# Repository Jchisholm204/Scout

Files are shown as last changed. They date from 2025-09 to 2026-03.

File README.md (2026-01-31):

# Scout - Autonomous UAV Project

Scout is a quad rotor UAV capable of autonomous navigation in small spaces without the use of GNSS signals.
This is accomplished using a combination of SLAM and low level control algorithms for local and global positioning.

## Repo Organization
The base level of this repo is designed to follow the format of a ROS2 Project.
All code is encapsulated within ROS nodes within the [`src`](./src) folder.
Project documentation can found under [`docs`](./docs), while most other docs are placed with the code they are documenting.
Scripts, including build and launch scripts, can be found under [`scripts`](./scripts), while Python Launch files can be found under [`launch`](./launch).
Finally, the PCB design is available under [`PCB_Scout`](./PCB_Scout), and embedded code is placed under [`src/control_board`](./src/control_board/firmware)

## Building

### Dependencies
- ROS2 Humble
- arm-none-eabi-gcc
- CLANG/CLANG-15
- RViZ
- [Liftoff Steam Game](https://store.steampowered.com/app/410340/Liftoff_FPV_Drone_Racing/) (for running the simulation)

### Building ROS Nodes
The ROS build is handled by the [`build.sh`](./scripts/build.sh) script and the top level `Makefile`.
To build the ROS nodes, run:
```sh
make
```

To generate a clean build, run:
```sh
make clean all
```

#### Adding to the build
By default, the ROS build system is only configured to build the specified nodes for the current target system, set by the system `HOSTNAME`.
Package names listed under `PKGS_COMMON` will be built on all systems.
Some packages are platform specific, and thus are specified under `PKGS_{PLATFORM}`.
To add a platform, add a new hostname declaration, a new platform specific package list, and adjust the `if` condition at the bottom of [`build.sh`](./scripts/build.sh)

### Building Embedded Code
The embedded code is not built with the ROS nodes.
Do not attempt to add the embedded code to the ROS build system.
ROS will struggle to comprehend the cross compilation and linking used in the embedded codebase.

To build the embedded code, refer to the top level `Makefile` within the [Firmware](./src/control_board/firmware) folder.
After installing `arm-none-eabi-gcc`, the embedded code can typically be built and flashed with:
```sh
make build
# For Flashing using the Linux Open Source st-flash tool
make st-flash-lin
# For Flashing using the ST utility on Windows
make st-flash-win
# For Flashing using a black magic probe
make BlackMagic-flash
```

**Building on Windows:**
When building on Windows -w- VS Code, incorrectly configured environment variables can cause build environment to default to `MSVC` rather than the `arm-none-eabi` compiler.
This **will** cause the build to fail.

To resolve this error, either remove the `MSVC` compiler, or use the `CMakeLists` plugin within VS Code to correctly configure the compiler to `arm-none-eabi-gcc`.

## Simulation/HILT
Hardware In the Loop testing is possible through the Liftoff FPV Flight simulator.
First, download and install Liftoff from the [Steam Store](https://store.steampowered.com/app/410340/Liftoff_FPV_Drone_Racing/).
After installing, follow the directions within [Jchisholm/LiftoffSimulator](https://github.com/Jchisholm204/LiftoffSimulator) to build and install the required modifications.

Basic simulation is possible without installing the modifications, however, LiDAR data, along with the [`simulation/lidarstreams`](./src/simulation/lidarstreams) node will fail to function.

After Liftoff has been configured, launch the simulator, followed by the [`sim_rviz.py`](./launch/sim_rviz.py) Launch Script.
This script can be launched with:
```sh
ros2 launch ./launch/sim_rviz.py
```

After launching, RViZ should display the drone, along with simulated LiDAR data.
Note that with the current state of the simulation mod, the LiDAR data is directly correlated to the in-game camera angle.
Therefore, for accurate testing, set the in-game camera angle to zero (0).

## Flight Stack
### ROS
The highest level control algorithms.
Not designed to run in real-time (ROS cannot handle real-time scheduling).

### Control Board
Low Level Collision Avoidance and flight control algorithms.
The Control Board handles real-time flight kinematics based off of LiDAR data and feedback from the FC.

### INAV (FC)
The INAV project was used as the firmware for the flight controller.
The INAV stack handles the lowest level of flight kinematic control and motor control.

### Drone
 - SpeedyBeeF405 V4 FC
 - SpeedyBee 65A 3-6S ESC
 - 10" Frame
 - 800KVA Motors

### Jetson
 - Jetson Nano
 - Quad Core Cortex-A57
 - Nvidia Maxwell GPU (256 Cuda Cores)
 - Ubuntu 22.04.5 LTS "Jammy Jellyfish"

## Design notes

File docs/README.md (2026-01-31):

# Scout - Autonomous UAV Project
This page serves as the project homepage for the Autonomous UAV drone named Scout.

## Simulation
- [Liftoff Simulator](./Liftoff Simulator.md)
- [Simulation LiDAR Processing](./Embedded/Simulation LiDAR Processing.md)
## Embedded Control Board
- [Serial Layer](./Embedded/Serial Layer.md)
- [FreeRTOS](./Embedded/FreeRTOS.md)
- [Control Task](./Embedded/Control Task.md)
- [AntiGravity Controller](./Embedded/AntiGravity Controller.md)
- [USB Interface](./Embedded/USB Interface.md)
- [Crossfire Interface](./Embedded/Crossfire Interface.md)

## High-Level Control (ROS)

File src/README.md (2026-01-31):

# Packages
Each package contains relevant documentation in its directory.
See [this link](https://jchisholm204.github.io/posts/ros_project_templating/) for how to structure ROS packages/nodes.

### ([`control_board`](./control_board))
Contains the [embedded code](./control_board/firmware) and [driver](./control_board/driver) for the control PCB.
This board handles the low-level control and obstacle avoidance.

### [`simulation`](./simulation)
Contains the bridge code that allows ROS to interact with the Liftoff simulator.

### [`controllers`](./controllers)
High level controllers and control algorithms.
Includes planning algorithms.

### Interfaces (deprecated)
Interfaces used for interacting directly with sensors, removing the control board from the critical path.

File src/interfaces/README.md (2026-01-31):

# LEGACY
## Interfaces
The interfaces package handles all sensor/device interfacing.

### `inav_bridge`
The `inav_bridge` node handles interfacing ROS with INAV on the FC.
Receives generic `Vector3` commands on target angles to set the drone to.
Publishes IMU, Gyro, RSSI, and other data.
#### Deps
- libmsp (included in the project directory as a git submodule)

#### Parameters
- `fc_path`:
    - Desc: UNIX file path to the FC file descriptor
    - Type: `std::string`
    - Default: `/dev/ttyACM0`
- `fc_baud`:
    - Desc: Baud rate to use when interacting with the FC
    - Type: `uint64_t`
    - Default: `921600`
- `wd_timeout`:
    - Desc: Watch-Dog timeout value
    - Type: `uint64_t` (ms)
    - Default: `500`
- `pub_prefix`:
    - Desc: Prefix applied to all ROS/INAV messages
    - Type: `std::string`
    - Default: `inav`
- `movement_topic`:
    - Desc: Topic name to receive movement messages (`Vector3`)
    - Type: `std::string`
    - Default: `movement`
- `arm_topic`:
    - Desc: Topic name to receive arming messages over (`Bool`)
    - Type: `std::string`
    - Default: `armed`
- `fall_time`:
    - Desc: Time (in s) to allow the drone to fall on low throttle before shutting down during failure.
    - Type: `uint64_t` (seconds)
    - Default: `5`
- `fall_speed`:
    - Desc: Throttle speed to use when falling during failure
    - Type: `uint64_t`
    - Default: `1500`
    - Max: `2000`
    - Min: `0`

#### Topics
All topics are published with the naming convention `/prefix/topic`.
- `imu`: Gravity Readings in x, y, z format
- `gyro`: Rotational Readings in yaw, pitch, roll format
- `quat`: Orientation of the drone in quat format
- `batt`: Battery State (Voltage, Current, mAh used)
- `motor_speed`: Motor Speed (in RPM) reported by the ESC
- `altitude`: Barometric Altitude Reading
- `rssi`: RSSI Signal Strength (0-100%)

### `rplidar_bridge`
Handles interfacing between the RPLiDAR and ROS.

#### Parameters
- `lidar_path`:
    - Desc: UNIX File path to the LiDAR file descriptor
    - Type: `std::string`
    - Default: `/dev/ttyUSB0`
- `lidar_baud`:
    - Desc: Baud rate to use with the LiDAR (Change with Caution)
    - Type: `uint64_t`
    - Default: `460800`
- `pub_prefix`:
    - Desc: Publish Prefix (lidar topic name)
    - Type: `std::string`
    - Default: `lidar`
- `frame_id`:
    - Desc: Base Frame ID for RVIZ
    - Type: `std::string`
    - Default: `map`
- `pub_rate`:
    - Desc: Lidar Message Publish rate (in ms)
    - Type: `uint64_t`
    - Default: `50`
    - Max: `1000`
    - Min: `10`
- `lidar_mode`:
    - Desc: Lidar Mode to be used
    - Type: `uint64_t`
    - Default: `0`
    - Max: Depends on model of LiDAR
    - Min: `0`

#### Topics
- `$(pub_prefix)`: Laser Scan message with LiDAR Data

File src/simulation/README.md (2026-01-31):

# Simulation - Liftoff Simulator Bridge
This package acts as a bridge between the Liftoff FPV flight simulator and ROS.

To read more about how to set up the simulator, see [this writeup](https://jchisholm204.github.io/posts/liftoffsim/).

## `simulation/control`
The simulation control node serves to inject control node into the Liftoff Simulator.
It does this by emulating a virtual controller device that Liftoff sees as a generic joystick.

To send commands to the Simulator, create a node that publishes a `geometry_msgs::Quaternion` message with the format:
```
x: forwards velocity
y: sideways velocity
z: vertical velocity
w: rotational velocity
```
The control node expects that all values within the Quaternion are capped between [-1, 1].

### Parameters
- `crtl_topic`: string - topic name to listen to control commands on

### Topics
- `ctrl_topic`: Quaternion - Control Command

## `simulation/lidarstreams`
The simulation `lidarstreams` node relays UDP LiDAR data outputs from the Liftoff simulator into the ROS network in the form of Laser Scan messages.

### Parameters
- `lidar_front_name`: string - topic name for the front LiDAR
- `lidar_vertical_name`: string - topic name for the vertical LiDAR
- `pub_rate`: milliseconds (int) - the rate at which LiDAR messages are published

### Topics
- `lidar_front_name`: `LaserScan` - Front LiDAR Laser Scan (pub)
- `lidar_vertical_name`: `LaserScan` - Vertical LiDAR Laser Scan (pub)

## `simulation/telemetry`
Publishes the Telemetry information from the Liftoff Simulator as ROS Telemetry messages

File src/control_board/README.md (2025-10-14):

# Control Board

## Include
Shared `include` directory for embedded and driver sides.

## Driver
ROS side driver code.

## Firmware
Embedded STM32 Firmware.
This code must not be compiled with ROS.

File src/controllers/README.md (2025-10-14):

## Controllers
The Controllers package handles all the control algorithms applied to the drone.

### `gravitational`
Gravitational based motion controller.
Accepts in a directional vector on where to move.
Produces stick outputs that can be applied to the drone.
Uses Lidar data avoid objects.

#### Parameters
- `imu_topic`:
    - Desc: Topic name of the IMU topic
    - Type: `std::string`
    - Default: `/inav/imu`
- `gyro_topic`:
    - Desc: Topic name for the drone gyro
    - Type: `std::string`
    - Default: `/inav/gyro`
- `battery_topic`:
    - Desc: Topic name for the drone battery
    - Type: `std::string`
    - Default: `/inav/batt`
- `motor_topic`:
    - Desc: Topic name for the drone motor average rpm
    - Type: `std::string`
    - Default: `/inav/mtr`
- `altitude_topic`:
    - Desc: Topic name for the drone barometric altitude
    - Type: `std::string`
    - Default: `/inav/altitude`
- `hor_lidar_topic`:
    - Desc: Topic name the horizontal LiDAR data
    - Type: `std::string`
    - Default: `/lidar`
- `ver_lidar_topic`:
    - Desc: Topic name the vertical LiDAR data
    - Type: `std::string`
    - Default: `/verdar`
- `target_topic`:
    - Desc: Topic name to listen for target positions on
    - Type: `std::string`
    - Default: `/gtarget`
- `movement_topic`:
    - Desc: Topic name top send out drone movement commands on
    - Type: `std::string`
    - Default: `/inav/movement`
- `arming_topic`:
    - Desc: Topic name top send out drone arming commands on
    - Type: `std::string`
    - Default: `/inav/armed`
- `collide_max`:
    - Desc: Maximum range value to consider points for collision detection
    - Type: `float` (meters)
    - Default: `0.8f`
- `hover_alt`:
    - Desc: Minimum distance from the ground to overcome ground effects
    - Type: `float` (meters)
    - Default: `0.5f`
- `log_level`:
    - Desc: Logging Level to use
    - Type: `std::string` [`none`, `info`, `warning`, `error`]
    - Default: `none`
- `horizontal_weight`:
    - Desc: Weighting applied to horizontal LiDAR readings
    - Type: `float` (meters)
    - Default: `1.0f`
- `vertical_weight`:
    - Desc: Weighting applied to vertical LiDAR readings
    - Type: `float` (meters)
    - Default: `1.0f`
- `target_weight`:
    - Desc: Weighting applied to the target position 
    - Type: `float` (meters)
    - Default: `1.0f`
- `hover_weight`:
    - Desc: Weighting applied to the hover distance
    - Type: `float` (meters)
    - Default: `1.0f`

#### Topics
- `[movement_topic]`: Publishes stick commands
- `[arming_topic]`: Topic to send the arming messages over
- `[target_topic]_mk`: Publishes a `visualization_msgs::msg::Marker` for Rviz compatibility

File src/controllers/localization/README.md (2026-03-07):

# Localization Controller

Operates on LiDAR points from either the drone or simulation to generate "walls."
Walls are either "valid," representing free space, or "invalid," representing actual physical walls seen by the LiDAR sensors.

**Requires:**
The `laser_segmentation` node to be online.

The `laser_segmentation` node generates a base set of segments from the LiDAR data.
This node uses that data to generate "walls" by merging and separating segments.
This node also applies a hysteresis filter to smooth out jumpy walls and prevent false positives for unexplored areas.

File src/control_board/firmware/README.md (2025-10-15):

# Scout - Central Control Board

USB Operated control board for the Scout Capstone Project.

- Control interfaces are exposed over a USB CDC interface build with the IAD mechanism.
- Virtual COM port implemented for error feedback through USB CDC (IAD)

## USB Device Specifications
(exposed from the viewpoint of the host as per USB IF specifications)
- Vendor ID: 0xFFFE
- Product ID: 0x0A4D
- Virtual COM port (CDC)
    - NTF Interface Number: 0x00
    - Data Interface Number: 0x01
    - Data RX EP: 0x01
    - Data TX EP: 0x81
    - Maximum Data Packet Size: 0x40
    - NTF EP: 0x82
    - Maximum NTF Packet Size: 0x08
- Control Endpoint (CDC)
    - NTF Interface Number: 0x02
    - Data Interface Number: 0x03
    - Data RX EP: 0x03
    - Data TX EP: 0x83
    - Maximum Data Packet Size: 0x40
    - NTF EP: 0x84
    - Maximum NTF Packet Size: 0x08

## Firmware
The application firmware is located under `core`.
Documentation for working within the core is in [`core/README.md`](./core/README.md).

### Dependencies
- FreeRTOS (`FreeRTOS/`)
- CMSIS (`vendor/`)
- GNU Make
- CMake
- ARM GCC Cross-Compiler

> [!WARNING]
> You must install the `arm-none-eabi` tool-chain before attempting to build.
> This tool-chain can be found on the [ARM Developer Website](https://developer.arm.com/downloads/-/gnu-rm)

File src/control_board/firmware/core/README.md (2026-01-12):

# Core Code README
The "Core Code" encompasses all application specific code.
For boot sequence or linker documentation, see the [Vendor Documentation](../vendor/README.md).
For FreeRTOS documentation, see the [FreeRTOS Website](https://www.freertos.org/).

## Configuration
Located under `include/config/`, there are many configuration files used for the HAL, OS, and pin-maps.

### Boards
The boards folder, located under `include/config/boards`, gives developers an opportunity to easily test code on multiple boards.
To add to the boards list, first create the board and its pin-maps following the format from the existing boards.
Then, add the board to the list of boards under `include/config/pin_cfg.h`.

### NVIC
Contains the Nested Vector interrupt Controller (NVIC) configuration.
Messing with this file can cause FreeRTOS stalls and hard faults.

## OS
Files part of the OS include the FreeRTOS Scheduler, `C` files under the OS folder in `src`, and the HAL.
Additionally, the `FreeRTOSConfig.h` file under `include/config`.

Any file falling in the OS category should not be modified.
These files allow the base system to function correctly.
Modifying them could introduce unintended errors or faults that are difficult to diagnose.

### StdIO
To configure the Standard Input/Output port, use the function `register_stdio` provided by `syscalls.h`.
This function should be called once by the main function.
If not initialized, IO calls such as `printf` will return an error.

## Drivers
Drivers are the middleware.
They exist to provide access control between FreeRTOS tasks and the STM32 hardware.
The is project contains UART, CAN, and USB Drivers.
The drivers folder should contain only STM32 drivers that interact with the STM32 HAL.
Other drivers, such as device drivers, should be placed under [interfaces](#interfaces).

### UART
The UART driver, titled `Serial`, acts as a middleware allowing UART ports to be shared between FreeRTOS Tasks.
The Serial layer also enables `C` functions such as `printf`.
To use a Serial port for printf, initialize it in `main.c`, then initialize it as the standard IO port via `register_stdio`.

Writing to UART is a blocking operation.
Writing can be performed through the Serial Driver layer, which contains an access mutex.
Therefore, Serial ports can be shared between multiple FreeRTOS Tasks.

To read from a UART port, create a [FreeRTOS Stream Buffer](https://freertos.org/Documentation/02-Kernel/04-API-references/08-Stream-buffers/00-RTOS-stream-buffer-API).
The buffer should be created statically, and set up for whatever application specific purpose is needed.
To attach the buffer to the Serial port, call `serial_attach`.
Only one FreeRTOS task may attach a read buffer at the same time.
Read buffers are filled on UART interrupts, which are enabled automatically when a buffer is attached, and disabled automatically when a buffer is detached.

> **Update:** *(Jan 12, 2026)*
> The Serial layer was changed from being globally accessible to a private implementation.
> This is to reduce the risk of code errors and interfering writes for devices that operate over UART.
> The CAN Layer has not yet had this change applied.

### CAN
The CAN Bus driver allows tasks to register `CanMailbox_t` structures with it.
A mailbox is tailored to a specific CAN ID.
When a CAN Bus interrupt occurs, the message is forwarded to the CAN Task, which then deposits messages into mailboxes.
Tasks can read from the mailbox at any time, or block waiting for an RX event with `can_mailbox_wait`.
Tasks may choose to block indefinitely waiting for an RX event.
If blocking waiting for an RX event, the task will be woken up once the CAN task has finished.
The CAN task can register a maximum of `MAX_MAILBOXES`.
Adjust this define statement to enable more mailboxes.
This will use additional memory.

### USB
The USB Drivers used in this project are from the libusb_stm32 library.
Most of the USB Driver and HAL are directly taken from the USB CDC Demo project.
Only minor modifications have been made to the library in this project.
See [this GitHub repository for more information.](https://github.com/dmitrystu/libusb_stm32)

## User Code

### Protocols
The protocols folder has been set aside for application specific drivers and protocols.
This should not be confused with the `drivers` folder, which is used for system level drivers.

### Tasks
All user tasks should be placed within the `tasks` folder.

All tasks should follow the same generic base structure:

```c
typedef struct {
    TaskHandle_t tsk_hndl;
    StaticTask_t tsk_buf;
    StackType_t tsk_stack[STACK_SIZE];
    ...
} myTask;

void *myTask_init(myTask *, ...){
    ...
    xTaskCreateStatic(...);
    ...
}
```

This structure allows all task data and runtime nonsense to be statically initialized in main.

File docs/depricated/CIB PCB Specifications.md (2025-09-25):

The Central Interface Board (CIB) handles low level drone operation including collision avoidance, flight execution, and system monitoring.
*Note: Flight kinematics are out of the scope for this board.*

# Interfaces
- 1x USB FS (over USBC) [[CIB USB Spec]]
	- PG Excluded
- 6x UART/USART (with 5V PG)
	- 2x RPLidar Connections [[RPLiDAR]]
	- 1x MSP connection
	- 1x CRSF OUT connection
	- 2x Debug/EPS
- 8x analog
	- Scaling voltage dividers for up to 8S battery monitoring
- 5V5A generic power connection (for Jetson Nano)

## Battery Monitoring
Multi cell batteries typically contain balance leads.
For a 4S battery, the lead pattern would be as follows:
- GND
- 4.2V
- 8.4V
- 12.6V
- 16.8V
For any battery with a higher number of cells, the pattern continues increasing 4.2V (Max cell voltage) for every connection.
The battery monitor must use the correct voltage dividers to accurately sample battery cell voltages.

# Chips
- An `STM32F446` should be used as the MCU.
- LLS's are not required for CSRF, RPLiDARS, or FC interactions.
- An IMU with internal filtering should be selected

# Power
The voltage rails and connected devices are listed below with amperage requirements
- VBatt
	- Drone (~A)
- 5V0
	- Jetson (5A)
	- 2x RPLidar (4A)
	- CSRF Module (500mA)
- 3V3
	- STM32F446 (1A)

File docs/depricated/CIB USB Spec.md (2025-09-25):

# Device Specifications
- Vendor ID: `0xFFFE`
- Product ID: `0xD40E`
# EP Specifications
The following lists the endpoint specifications for the USB interface.
RX/TX pairs are listed from the perspective of the host as per USB IF specifications.
## Control/Planning (CDC ACM)
- NTF Interface Number: `0x00`
- Data Interface Number: `0x01`
- Data RX EP: `0x01`
- Data TX EP: `0x81`
- Maximum Packet Size: `0x40`
- NTF EP: `0x82`
- Maximum NTF Packet Size: `0x08`
### TX Interface
- Target Type - `(u8)enum`
	- Velocity - Sets the target velocity of the drone
	- Positional - Sets the target position of the drone
	- Hold - Drone will ignore position and attempt to hold the current position
- Target X - `float32`
- Target Y - `float32`
- Target Z - `float32`
- Target W (yaw) - `float32`
- Flags
	- Arm Drone
	- Disarm Drone
	- Reset 1
	- Reset 0
	- Execute Fail Safe
	- Valid 0
	- Valid 1
### RX Interface
- $A_x$ (Acceleration in X) - `float32`
- $A_y$ (Acceleration in Y) - `float32`
- $A_z$ (Acceleration in Z) - `float32`
- $A_w$ (Acceleration in W) - `float32`
- Battery Voltage - `float32`
- Flags - `u8`
	- Stopped before Collision
	- Drone Armed
	- FC Error
	- CIB Error
	- Valid 0
	- Valid 1

## RPLiDAR Hor
Forwards the RPLiDAR data from the horizontal lidar.
- NTF Interface Number: `0x02`
- Data Interface Number: `0x03`
- Data RX EP: `0x03`
- Data TX EP: `0x83`
- Maximum Packet Size: `0x40`
- NTF EP: `0x84`
- Maximum NTF Packet Size: `0x08`
## RPLiDAR Ver
Forwards the RPLiDAR data from the vertical lidar.
- NTF Interface Number: `0x04`
- Data Interface Number: `0x05`
- Data RX EP: `0x05`
- Data TX EP: `0x85`
- Maximum Packet Size: `0x40`
- NTF EP: `0x86`
- Maximum NTF Packet Size: `0x08`

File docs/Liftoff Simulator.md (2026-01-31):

Liftoff is first-person drone racing simulator designed for human pilots to explore flying.
To test autonomous drone control, I repurposed Liftoff to act as a high-fidelity testing environment.

While liftoff is designed primarily for human pilots, it can be configured to expose basic telemetry data over UDP.
Additionally, the game is written in Unity, allowing further data to be exposed through modifying the game files.
Finally, control input can be supplied to the game through a virtual controller.
Therefore, the game can be used as a hyper-realistic simulator for testing autonomous flight control algorithms.

## Basic Telemetry Output
By default, Liftoff can be configured to expose basic telemetry data.
For a full explanation on how to enable Liftoff's drone telemetry feature, see [this post on the Steam community forum.](https://steamcommunity.com/sharedfiles/filedetails/?id=3160488434)

On Linux, all telemetry data can be exposed by placing the following inside of  `~/.config/unity3d/LuGus Studios/Liftoff/TelemetryConfiguration.json`.

```json
{ 
	"EndPoint": "127.0.0.1:9001", 
	"StreamFormat": [ 
		"Timestamp", 
		"Position", 
		"Attitude", 
		"Velocity", 
		"Gyro", 
		"Input", 
		"Battery", 
		"MotorRPM" 
	] 
}
```

Liftoff data can then be retrieved reading data from the UDP connection into the following C structure.

```c
#pragma pack(push, 1) // Critical for network packet alignment
typedef struct {
    float timestamp;              // 4 bytes
    float posX, posY, posZ;       // 12 bytes
    float rotW, rotX, rotY, rotZ; // 16 bytes (Quaternions)
    float velX, velY, velZ;       // 12 bytes
    float gyroP, gyroR, gyroY;    // 12 bytes
    float inT, inY, inP, inR;     // 16 bytes
    float batPct, batVolt;        // 8 bytes
    uint8_t motorCount;           // 1 byte
    float motors[4];              // 16 bytes (for a quad)
} lf_telemetry_packet_t;
#pragma pack(pop)
```

Note that the following socket configuration is required to ensure that the most recent packet is always read by the receiving program.

```c
int buffer_size = sizeof(lf_telemetry_packet_t); 
// Only hold one packet's worth of data
setsockopt(tel->sockfd, SOL_SOCKET, SO_RCVBUF, &buffer_size, sizeof(buffer_size));
```

Without the above configuration, the UDP socket buffer may fill up, causing the simulator data to become out of sync with Liftoff.
Through setting the socket buffer to be exactly the size of one packet, the program will always read the latest data sent from Liftoff.

## Mods + Extracting LiDAR Data
To be able to test autonomous flying algorithms, we must be able to retrieve simulated LiDAR data from the game.
While this data is not exposed by default, it can be through injecting a mod into the game.

The following mod exposes two LiDAR streams over a single UDP port.
The LiDAR data is exposed over the following format:

```c
#define N_POINTS 180
#define PORT 9002

struct lidar_packet {
    float front[N_POINTS];
    float vertical[N_POINTS];
};
```

The "front" LiDAR stream refers to the simulated LiDAR mounted on the top of the drone.
This sensor returns a scan of 180 evenly spaced points starting at the front of the drone, wrapping around the right, back, left and returning to the front.
The "vertical" LiDAR stream refers to the simulated LiDAR mounted on the back of the drone.
This sensor is mounted upright, and returns 180 evenly spaced points covering the top, sides, and bottom.

The orientations of the sensors can be reconfigured by changing the mod.
However, they are chosen such that the drone can use the vertical sensor to remain centered within an enclosed space while using the front sensor to avoid obstacles in its path.

### Installing The Mod
To install the mod, first download [BepInEx](https://github.com/bepinex/bepinex/releases) from its releases page and follow the install instructions.
On Linux, this consists of extracting the BepInEx folder and placing it inside of  `~/.local/share/Steam/steamapps/common/Liftoff`.
After extracting, create the `plugins` folder inside of the `BepInEx` folder.

#### BePinEx Configuration
Once BepInEx is installed, some configuration values must be changed, the most important of which is ensuring that the mod is hidden from Unity.
Without this, the mod will fail to work.
To hide the mod from Unity, change the `[Chainloader]` section of `BepInEx/config/BepInEx.cfg` to match the following:
```
[Chainloader]

## If enabled, hides BepInEx Manager GameObject from Unity.
## This can fix loading issues in some games that attempt to prevent BepInEx from being loaded.
## Use this only if you know what this option means, as it can affect functionality of some older plugins.
## 
# Setting type: Boolean
# Default value: false
HideManagerGameObject = true
```

Additionally, disabling mod caching has also been found to help resolve some issues.
```
[Caching]

## Enable/disable assembly metadata cache
## Enabling this will speed up discovery of plugins and patchers by caching the metadata of all types BepInEx discovers.
# Setting type: Boolean
# Default value: true
EnableAssemblyCache = false
```

#### Building/Loading the Mod
To start receiving LiDAR data from the game, clone the mod from its [GitHub](https://github.com/Jchisholm204/LiftoffSimulator/tree/main) repository.
Once cloned, build the mod with:

```
cd LidarMod/LiftoffLidar && dotnet build
```

Finally, copy the built executable from the build folder to the BepInEx plugins folder:

```
cp ~/Documents/LiftoffSimulator/LidarMod/LiftoffLidar/bin/Debug/netstandard2.1/LiftoffLidar.dll ~/.local/share/Steam/steamapps/common/Liftoff/BepInEx/plugins`
```

> **WARNING:**
> Do not attempt to symlink the mod.
> Symlinking will cause the mod to fail to load into the game.
{:.prompt-warning}

After completing the above, the game can be launched and the LiDAR data can be received over UDP.
Again, use the aforementioned UDP port configuration to ensure that LiDAR data is not buffered.

### Configuring The Mod
The mod files are open source at [GitHub/Jchisholm204/LiftoffSimulator](https://github.com/Jchisholm204/LiftoffSimulator/blob/main/LidarMod/LiftoffLidar/Plugin.cs).
They can be freely modified to suit any purpose.
The two primary modifications one may choose to make are modifying the number of LiDAR points and changing the mount angles.

#### Changing The Number of LiDAR Points
The number of LiDAR points is configurable with the following constant:

```cs
private const int N_POINTS = 180;
```

Note that changing this number may result in the LiDAR array being larger than a single UDP packet.

#### Changing the LiDAR Angles
To change the LiDAR angles, the following lines can be changed:

```cs
// Scan forward and to the sides
Vector3 direction = Quaternion.AngleAxis(i*(360f/N_POINTS), drone.transform.up) * drone.transform.forward;

...

// Scan up and to the sides
direction = Quaternion.AngleAxis(i*(360f/N_POINTS), drone.transform.forward) * drone.transform.up;
```

Note that Liftoff uses the `XZY` coordinate system, that is Y is upwards.

### Extra Notes
Given that the Liftoff developers cannot be asked to support modding their game, the game object of focus for the LiDAR data was found through trial and error.
This resulted in the `DroneHUD_Custom(Clone)` game object being used as the "mounting" point for the virtual LiDARs.

It is important to note that this game object is tied to the camera angle.
This means that that camera angle must be set to 0 deg by pressing the down arrow after the game launches.

## Game Input / Virtual Controller
The final step in using Liftoff as a simulation tool is to create a mechanism that allows the algorithm to control the virtual drone.
This was done through creating a virtual controller device using the Linux `uinput` library.

To achieve this result, the `joystick` code can be copied from the same GitHub repository as the mod.
The following functions are available and are fairly self explanatory:

```c
enum axis {
    AXIS_THROTTLE = ABS_X,
    AXIS_YAW = ABS_RX,
    AXIS_PITCH = ABS_Z,
    AXIS_ROLL = ABS_Y,
};

extern int joystick_init(struct joystick *joy);
extern int joystick_write(struct joystick *joy, enum axis axis, int value);
extern int joystick_close(struct joystick *joy);
```

## Optional - ROS Nodes
As part of Project Scout, several ROS nodes were written to expose Liftoff Simulator data on the ROS network.
These nodes can be found on the [Scout GitHub Repository.](https://github.com/Jchisholm204/Scout/tree/main/src/simulation)
All nodes related to Liftoff can be found within the `simulation` package.

### Control Node
The control node can be used to inject control data into Liftoff using the virtual controller code from the previous section.
The control node accepts a Quaternion message containing values between -1 and 1 where -1 is the minimum value, 1 is the maximum, and 0 is the center point.

The Quaternion message is processed by the node as follows:
```cpp
joystick_write(&_joy, AXIS_THROTTLE, qt.z * AXIS_MAX);
joystick_write(&_joy, AXIS_YAW, qt.w * AXIS_MAX);
joystick_write(&_joy, AXIS_PITCH, qt.y * AXIS_MAX);
joystick_write(&_joy, AXIS_ROLL, qt.x * AXIS_MAX);
```

### LiDAR Node
The LiDAR node, titled `lidarstreams` publishes the Liftoff LiDAR data as two `LaserScan` messages.
The node can be configured with the following configuration values:

```cpp
this->declare_parameter("lidar_front_name", "lidar_front_frame");
this->declare_parameter("lidar_vertical_name", "lidar_vertical_frame");
this->declare_parameter("pub_rate", 50);
```

### Launch File
To view LiDAR data inside of RVIZ, the following launch script can be used.
This launch file will also load a drone model inside of RVIZ, and setup the control node.

> **WARNING:**
> Do not attempt to launch the `simulation/control` node with a controller plugged in.
> If the control node is launched while a physical controller is connected, it can cause a glitch within the game.
> This glitch will result in no controllers being found.
> To resolve this glitch, close everything and restart.
{:.prompt-warning}

```python
from launch import LaunchDescription
from launch.actions import DeclareLaunchArgument
from launch_ros.actions import Node
from ament_index_python.packages import get_package_share_directory
import os

def generate_launch_description():
    # 1. Setup Paths
    package_dir = get_package_share_directory("simulation")
    urdf_path = os.path.join(package_dir, 'udrf', 'sjtu_drone.urdf')

    with open(urdf_path, 'r') as f:
        robot_desc = f.read()

    return LaunchDescription([
        DeclareLaunchArgument('use_sim_time', default_value='false'),

        # Node: Robot State Publisher (Visualizes the drone)
        Node(
            package='robot_state_publisher',
            executable='robot_state_publisher',
            name='robot_state_publisher',
            parameters=[{'robot_description': robot_desc}]
        ),

        # Node: Static TF for LIDAR 1 (Front/Sides)
        # Arguments: x y z yaw pitch roll parent_frame child_frame
        Node(
            package='tf2_ros',
            executable='static_transform_publisher',
            name='tf_lidar_front',
            arguments=['0.1', '0', '0', '0', '0',
                       '0', 'base_link', 'lidar_front_frame']
        ),

        # Node: Static TF for LIDAR 2 (Above/Below/Sides)
        # We might rotate this one 90 degrees (1.5708 radians) on the pitch or roll axis
        Node(
            package='tf2_ros',
            executable='static_transform_publisher',
            name='tf_lidar_vertical',
            arguments=[
                '--x', '0.15',
                '--y', '0',
                '--z', '0.05',
                '--yaw', '0',
                '--pitch', '-1.5708',
                '--roll', '0',
                '--frame-id', 'base_link',
                '--child-frame-id', 'lidar_vertical_frame'
            ]
        ),

        # Node: Launch RViz
        Node(
            package='rviz2',
            executable='rviz2',
            name='rviz2',
            output='screen',
            arguments=['-d', './rviz_sim.rviz']
        ),
        # Launch the simulation interfaces
        Node(
            package='simulation',
            executable='control',
            name='sim_ctrl',
            ),
        Node(
            package='simulation',
            executable='lidarstreams',
            name='sim_lidar',
            ),
    ])
```

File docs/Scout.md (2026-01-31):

# Scout - Autonomous UAV Project
This page serves as the project homepage for the Autonomous UAV drone named Scout.

## Simulation
- [[Liftoff Simulator]]
- [[Simulation LiDAR Processing]]
## Embedded Control Board
- [[Serial Layer]]
- [[FreeRTOS]]
- [[Control Task]]
- [[AntiGravity Controller]]
- [[USB Interface]]
- [[Embedded Data Flow.canvas]]
- [[Crossfire Interface]]

## High-Level Control (ROS)

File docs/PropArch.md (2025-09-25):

# Proposed Architecture
The following document outlines one possible architecture for the autonomous UAV as presented in [Project Specifications](./spec.md)

Each header within this document specifies the functions that a particular device will be responsible for completing.
The headers are organized from top to bottom in terms of information flow within the stack.

## ROS/HLS
- Runs on the Jetson
- Localization/Mapping  
    - Intel RealSense + SLAM
- Exploration Algorithm
    - Graph Based exploration algorithm that outputs target coordinates or velocities
- Positional Controller
    - Works with/for exploration algorithm (Could be combined)
    - Turns coordinates to velocities for where to move

## Jetson
- Runs ROS software
- Connects to CIB (Control Interface Board) over USB
- Connects to Intel RealSense over USB

## CIB (Control Interface Board)
- STM32 PCB
- Connects to LiDARs over UART
- Connects to Jetson/ROS over USB
    - Passes LiDAR data back over USB CDC-ACM(If needed for visualization)
    - Exposes custom CDC-ACM interface for directional control
- Handles Gravitational Control Algorithm/Obstacle Avoidance
    - Receives velocity command from higher level software
    - Uses LiDAR Data to avoid collisions
    - Manages throttle compensation to maintain altitude
- Connects to FC over MSP or CRSF or both
- Additional PCB Functionality
    - Possibly performs some kind of battery sensing/management
    - Provides a 5V5A power source for the Jetson
    - Connection for GPS (Future Use, Extra Serial always good)

## FC (Flight Controller)
- Receives stick commands over MSP or CSRF from the CIB
- Handles low level flight kinematics/control
- Interfaces with the ESC (DSHOT or Bidirectional DSHOT)

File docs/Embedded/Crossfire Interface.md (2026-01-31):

Crossfire (CRSF) is a high level communication protocol developed by Team Black Sheep (TBS) for transmitting control and telemetry data between a receiver and Flight Controller (FC). Originally intended for use in TBS devices, the protocol is now implemented in nearly every FC firmware and is used by most off-the-shelf receivers including ExpressLRS and Tracer.

This article serves as an introduction to the CRSF protocol ([Skip Ahead](#CRSF Protocol Basics)) and as documentation for my FreeRTOS Queue based implementation of a CRSF packet encoder/decoder ([Skip Ahead](#FreeRTOS Interface Implementation)).

## CRSF Protocol Basics
Crossfire (CRSF) is a high-speed, low latency communication protocol for sending and receiving control and telemetry data between a drone and controller.

The following section will focus on the CRSF packet structure, device addressing, base message types, and how to format a CRSF message for transmission.

### CRSF Packet Structure
The basic structure of every CRSF packet is identical, consisting of an address, length, type, payload, and CRC.

```
<address> <length> <type> <payload ... > <CRC>
```

The address, length, type, and CRC are each one byte (8 bits).
The payload can range from $2$ to $62$ bytes to accommodate various message formats.
Note that the length field excludes the address.
Therefore, length is calculated as:
$$Len(payload) + Len(type) + Len(CRC) = Len(payload)+2$$
Additionally, the CRC is calculated on only the type and payload, excluding the address and length bytes.

### Device Addressing
Each CRSF message contains an "address" field, denoting the address of the transmitting/receiving device.
The primary address used is `0xC8`, corresponding to the flight controller.
This address must be used when sending/receiving messages to/from the flight controller.
Other possible addresses are shown in the table below:

| Address | Device Description |
| --- | --- |
| 0x00 | Broadcast address |
| 0x10 | USB Device |
| 0x12 | Bluetooth Module |
| 0x80 | TBS CORE PNP PRO |
| 0x8A | Reserved |
| 0xC0 | PNP PRO digital current sensor |
| 0xC2 | PNP PRO GPS |
| 0xC4 | TBS Blackbox |
| 0xC8 | Flight controller |
| 0xCA | Reserved |
| 0xCC | Race tag |
| 0xEA | Radio Transmitter |
| 0xEB | Reserved |
| 0xEC | Crossfire / UHF receiver |
| 0xEE | Crossfire transmitter |

### Message Types
The CRSF protocol contains message types for both control and telemetry data.
The following section outlines the base message types used by INAV and Betaflight.
Custom message types can be used, but require implementation on the FC side.

> **NOTE**
> The number next to the each message is its ID in hex.
{:.prompt-tip}

#### RC Message (`0x16`)
The Remote Control (RC) message can be used to transmit stick commands from a device or receiver to the flight controller.
The RC message supports up to 16 RC channels.
Each channel is 11 bits and the 16 channels are packed into a 22 byte format.
The message format is shown below:

```c
struct rc_channels_msg{
	unsigned int chnl1 : 11;
	unsigned int chnl2 : 11;
	unsigned int chnl3 : 11;
	...
	unsigned int chnl16 : 11;
};
```

Many receivers and FC firmware's represent channels using $\mu$s.
CRSF however, uses ticks.
Therefore the following functions must be used to convert between the two measurements.

```c
TICKS_TO_US(x) ((x - 992) * 5 / 8 + 1500) 
US_TO_TICKS(x) ((x - 1500) * 8 / 5 + 992)
```

#### Link Statistics Message (`0x14`)
The link statistics message contains status information for the link between the receiver and the transmitter.
Uplink is the connection between the ground and UAV, downlink is the connection from the UAV to the ground station.

```c
struct __attribute__((packed)) {
    // dBm *-1
    uint8_t uplink_RSSI_1;
    // dBm *-1
    uint8_t uplink_RSSI_2;
    // percent
    uint8_t uplink_quality;
    // uplink SNR (db)
    int8_t uplink_SNR;
    // enum ant 1 = 0, 2
    uint8_t diversity_active_antenna;
    // enum Mode (4fps = 0, 50fps, 150Hz)
    uint8_t RF_mode;
    // enum (0mW, 10mW, 25mW, 100mW, 500mW, 1000mW, 2000mW)
    uint8_t tx_power;
    // dBm * -1
    uint8_t downlink_RSSI;
    // percent
    uint8_t downlink_quality;
    // db
    int8_t downlink_SNR;
} _crsf_link_t;
```

#### Battery Status Message (`0x08`)
The battery status message contains exactly the information one would expect.
Its format is as follows:

```c
typedef struct __attribute__((packed)) {
    // mV * 100
    uint16_t voltage;
    // mA * 100
    uint16_t current;
    // mAh (24 bits)
    unsigned int capacity : 24;
    // percent (0-100]
    uint8_t percent_remaining;
} _crsf_battery_t;
```

#### Flight Mode Message (`0x21`)
The flight mode message contains a null terminated string indicating the current flight mode of the FC.
This field is FC firmware dependent.
For Betaflight, the possible strings are covered under the [Betaflight CRSF Documentation.](https://www.betaflight.com/docs/wiki/guides/current/Telemetry#crossfire-protocol--crsf)

The message format is as follows:
```c
struct crsf_fcmode {
    char mode[];
};
```

#### Attitude Message (`0x1E`)
The attitude message contains the current pitch, yaw, and roll values from the flight controllers IMU.
All angles are represented in integer format, in $\frac{\text{radians}}{10,000}$.

```c
struct crsf_attitude_t{
    int16_t pitch;
    int16_t roll;
    int16_t yaw;
};
```

#### GPS Message (`0x02`)
Finally, the GPS message contains the current GPS information, if the drone has one.
The GPS message format is as follows:

```c
struct crsf_gps {
    // degrees / 10_000_000
    int32_t lattitude;
    // degrees / 10_000_000
    int32_t longitude;
    // km/h / 100
    uint16_t groundspeed;
    // degree / 100
    uint16_t heading;
    // meter - 1000m offset
    uint16_t altitude;
    uint8_t sat_count;
};
```

### Message Formatting
All of the `C` structures shown above conform to standard CRSF message types.
Thus, they can be directly used as payloads within the CRSF message format.

To format a CRSF message for transmission, first append the address (`0xC8` for the Flight Controller) and the length bits to the front of the message.
Again, note that the message length excludes the address byte.
Finally, calculate the 8-bit CRC using the $x^7+x^6+x^4+x^2+x^0$ hash and append it as the last byte in the message.

## FreeRTOS Interface Implementation
The following section serves as documentation for my FreeRTOS Queue-based implementation of a CRSF interface.
This interface is designed to completely abstract the CRSF interface, providing only read and write functions that return unpacked messages in standardized formats.
Furthermore, this implementation is designed to completely abstract the CRSF layer from any hardware constraints, relying only on FreeRTOS stream buffers.

The implementation is designed around the following features:
- Only using static memory defined within the `CRSF_t` structure
- Only reliant on FreeRTOS interfaces
- Independent from any hardware interfaces
- Minimal message buffering for low-latency and high throughput

### Initialization
The CRSF protocol itself does not require any initialization.
However, the implementation sets up an internal FreeRTOS task, used to parse the CRSF packets as bytes are delivered through the input stream buffer.

To initialize the `CRSF_t` structure, setup the queues, and create the internal task, the following function can be called:

```c
StreamBufferHandle_t crsf_init(CRSF_t *pHndl, StreamBufferHandle_t pTx_hndl) {
    if (!pHndl)
        return NULL;
    if (!pTx_hndl)
        return NULL;

    // Setup Write handle
    pHndl->tx.semphr_hndl =
        xSemaphoreCreateMutexStatic(&pHndl->tx.static_semphr);
    pHndl->tx.pBuf_hndl = pTx_hndl;

    // Setup Read Handle
    pHndl->rx.hndl = xStreamBufferCreateStatic(
        configMINIMAL_STACK_SIZE, 1, pHndl->rx.buf, &pHndl->rx.static_stream);

    // Setup the CRSF rx task
    pHndl->tsk.hndl = xTaskCreateStatic(vCRSF_Hndl_tsk,
                                        "CRSF",
                                        CRSF_STACK_SIZE,
                                        (void *) pHndl,
                                        2,
                                        pHndl->tsk.stack,
                                        &pHndl->tsk.static_tsk);
    if (!pHndl->tsk.hndl) {
        pHndl->state = eCRSFTskCreateFail;
        return NULL;
    }

    return pHndl->rx.hndl;
}
```

This function requires two arguments. First is the `CRSF_t` handle, which should be created statically at initialization time by whatever task "owns" the CRSF interface.
This handle contains all information required by the interface, including the FreeRTOS task and stack as well as internal data structures and semaphores.

The second argument required by the initialization function is a FreeRTOS stream buffer handle.
This handle is used to transmit messages, and must be initialized externally.
External initialization of this buffer allows its size and trigger values to be configured by whichever interface will be dealing with outbound packets.

Finally, the initialization function returns its incoming buffer in the form of another FreeRTOS stream buffer handle.
This buffer is used by the interface to receive and parse incoming packets.

### Reading CRSF Data
The CRSF interface automatically receives and and parses packets from its input buffer as the arrive.
This is done using the internal task that was setup by the initialization function.
Once parsed, incoming packets are stored within the `CRSF_t` structure such that they can be read by an outside task.
Note that after parsing, packets are not buffered, thus, only the most recent packet of each type is stored.
This ensures:
1. Only the most recent command/information can be read by an outside task.
2. Minimal memory overhead is needed to store the parsed packets.
3. Outside tasks do not need to block waiting for CRSF data

The following read functions are available:
```c
eCRSFError crsf_read_rc(CRSF_t *pHndl, crsf_rc_t *pChannels);
eCRSFError crsf_read_battery(CRSF_t *pHndl, crsf_battery_t *pBattery);
eCRSFError crsf_read_attitude(CRSF_t *pHndl, crsf_attitude_t *pAttitude);
eCRSFError crsf_read_mode(CRSF_t *pHndl, crsf_fcmode_t *pMode);
```

All read functions are non-blocking and thread safe.
Given that these functions return from the internal data structure, they can be called multiple times to return the same data.
Data is returned through the second parameter, and is transferred via copy.

### Writing CRSF Packets
Writing to the CRSF interface is a blocking operation.
For a task to write out a CRSF packet, it must wait to hold the transmit semaphore.

The following write functions are available:
```c
eCRSFError crsf_write_rc(CRSF_t *pHndl, const crsf_rc_t *pChannels);
eCRSFError crsf_write_battery(CRSF_t *pHndl, const crsf_battery_t *pBattery);
eCRSFError crsf_write_attitude(CRSF_t *pHndl, const crsf_attitude_t *pAttitude);
eCRSFError crsf_write_mode(CRSF_t *pHndl, const crsf_fcmode_t *pMode);
```

Each write function first copies the data from the normalized format to the CRSF format, ensuring that all data is properly formatted with the correct unit conversions.
The write function also ensures that minimum and maximum value constraints are not violated by clamping input data values.

After applying the data transformation, the following internal function is called to write the packet into the output buffer:
```c
eCRSFError _crsf_send_packet(CRSF_t *pHndl, _crsf_msg_t *msg, enum eCRSFMsgId id, uint8_t len) {
    if (!pHndl)
        return eCRSFNULL;
    if (!msg)
        return eCRSFNULL;

    if(len >= CRSF_DATA_MAXLEN){
        return eCRSFPktOverLen;
    }

    // Addr = CRSF Addr FC
    msg->addr = CRSF_ADDR;
    msg->length = len + 2; // type + payload + crc
    msg->type = (uint8_t) id;

    // CRC includes type and payload
    uint8_t crc = _crsf_crc8(&msg->type, len + 1);
    msg->pyld[len] = crc;

    if(xSemaphoreTake(pHndl->tx.semphr_hndl, 10) != pdTRUE){
        xStreamBufferSend(pHndl->tx.pBuf_hndl, msg, msg->length + 1, 10);
    }

    return eCRSFOK;
}
```

This function assumes that the length argument is the length of the data packet, allowing it to be called as shown below:

```c
struct _crsf_rc_t rc_msg = {0};
CRSF_t crsf_interface;
...
_crsf_send_packet(&crsf_interface, &rc_msg, eCRSFMsgRC, sizeof(struct _crsf_rc_t));
```

Note that the CRSF interface uses two types of packet formats.
Packet structures prefixed with `_` are used internally, and correspond to the exact formats defined within the CRSF protocol.
Structures without this prefix are designed to be used externally, are not "packed," and contain normalized values that are easier to work with.
For example, the CRSF protocol defines battery voltage as a uint16 in $mV *100$.
However, it is much easier to work with a standard measurement like $V$, represented as a floating point.

### Example Usage
The following code defines example usage for initializing the CRSF interface to operate over a Serial (UART) port.

```c
 // Create the write handle
 StreamBufferHandle_t tx_hndl = serial_create_write_buffer(pSerial, configMINIMAL_STACK_SIZE, 1, pHndl->tx_buf, &pHndl->tx_streamBuf);

StreamBufferHandle_t rx_hndl = crsf_init(&pHndl->crsf, tx_hndl);

if (!rx_hndl) {
    printf("CRSF INI Fail\n");
}

// Attach the read handle to the Serial interface
serial_attach(pHndl->pSerial, rx_hndl);
```

The above code first utilizes the Serial interface to create and initialize a new Serial write buffer.
Note that the FreeRTOS stream buffer memory is stored within `pHndl`, which is the handle of a test task containing both the serial driver and the CRSF interface.
While the Serial driver memory is owned by the Serial driver layer, and the receive buffer memory is owned by the CRSF layer, the transmit buffer memory must be owned by the encapsulating task.
In this case, that is the test task.

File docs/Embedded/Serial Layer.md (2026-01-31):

**Serial Layer:** A Thread safe STM32F446 UART driver implementation built using FreeRTOS.

## Initialization
Each serial interface can be initialized at most one time on an uninitialized USART (Serial) port.
Any calls to the initialization function on an initialized port will return `NULL`.
This behavior ensures that a Serial port can not accidentally be initialized by a second task, overriding its initial initialization and breaking program behavior.

To initialize a Serial port, the following function can be called.

```c
Serial_t *serial_init(eSerial serial,
                      unsigned long baud,
                      pin_t pin_rx,
                      pin_t pin_tx) {
    if (serial >= eSerialN) {
        return NULL;
    }

    // Retrive handle and ensure handle is not initialized
    Serial_t *pHndl = &SerialPort[serial];
    if (pHndl->state == eSerialOK)
        return NULL;

	// Initialize the hardware
    hal_uart_init(pHndl->UART, baud, pin_tx, pin_rx);
	
	// Create the write mutex
    pHndl->tx_hndl = xSemaphoreCreateMutexStatic(&pHndl->static_tx_semphr);
    if (pHndl->tx_hndl == NULL) {
        pHndl->state = eSerialInitFail;
        return NULL;
    }

    xSemaphoreGive(pHndl->tx_hndl);
    pHndl->state = eSerialOK;

    pHndl->tx_buf = NULL;
    pHndl->rx_buf = NULL;

    return pHndl;
}
```

The Serial initialization function returns a pointer to internal driver memory. 
This pointer can only be returned once through the first call of the initialization function.
Serial initialization can take place in either local or global scope, and the pointer can also be shared with multiple FreeRTOS tasks.

## Reading
To read from the Serial interface, tasks must attach a FreeRTOS Stream Buffer.
This buffer must be set up by the receiving task, and is automatically written to by the Serial device interrupts.
If the buffer is full when a byte is received on the UART interface, the Serial layer will drop the byte.

To attach a read buffer to the Serial interface, the following function can be called, which will initialize the hardware interrupt and add the buffer handle into the Serial data structure.

```c
eSerialError serial_attach(Serial_t *pHndl, StreamBufferHandle_t buf_hndl) {
    if (pHndl == NULL || buf_hndl == NULL)
        return eSerialNULL;
    if (pHndl->state != eSerialOK)
        return pHndl->state;
    if (pHndl->rx_buf == NULL) {
        pHndl->rx_buf = buf_hndl;
        NVIC_EnableIRQ(pHndl->IRQn);
        NVIC_SetPriority(pHndl->IRQn, NVIC_Priority_MIN);
        hal_uart_enable_rxne(pHndl->UART, true);
        return eSerialOK;
    }
    return eSerialSemphr;
}
```

## Writing
There are two ways to write to the serial interface: Direct blocking writes, and through a stream buffer.

### Direct Blocking Writes
If blocking writes are preferred, the following function can be called.
This function will not return until the write has completed.

```c
eSerialError serial_write(Serial_t *pHndl,
                          char *buf,
                          size_t len,
                          TickType_t timeout) {
    if (pHndl == NULL || buf == NULL)
        return eSerialNULL;
    if (pHndl->state != eSerialOK)
        return pHndl->state;
    if (xSemaphoreTake(pHndl->tx_hndl, timeout) == pdTRUE) {
        hal_uart_write_buf(pHndl->UART, buf, len);
        xSemaphoreGive(pHndl->tx_hndl);
        return eSerialOK;
    }
    return eSerialSemphr;
}
```

### Buffering Writes
The Serial driver also supports non-blocking, buffered writes through a FreeRTOS Stream Buffer.

To enable non-blocking, buffered writes, first create a buffer using the `serial_create_write_buffer` function.
This function is identical to `xStreamBufferCreateStatic`, but includes extra logic to setup the register the handler with the Serial interface and setup the UART interrupts.

```c
StreamBufferHandle_t serial_create_write_buffer(
    Serial_t *pSerial,
    size_t xBufferSizeBytes,
    size_t xTriggerLevelBytes,
    uint8_t *const pucStreamBufferStorageArea,
    StaticStreamBuffer_t *const pxStaticStreamBuffer) {
    if (!pSerial) {
        return NULL;
    }
    StreamBufferHandle_t hndl =
        xStreamBufferCreateStaticWithCallback(xBufferSizeBytes,
                                              xTriggerLevelBytes,
                                              pucStreamBufferStorageArea,
                                              pxStaticStreamBuffer,
                                              vSerial_RxCallback,
                                              NULL);
    if (!hndl) {
        return NULL;
    }
    pSerial->tx_buf = hndl;
    NVIC_EnableIRQ(pSerial->IRQn);
    NVIC_SetPriority(pSerial->IRQn, NVIC_Priority_MIN);
    return hndl;
}
```

The initialization function also registers a callback function that re-enables the UART interrupt whenever the buffer is written to.
Once enabled, the UART interrupt will drain bytes from the buffer until it is emptied.
Upon writing the last byte in the buffer, the UART interrupt is automatically disabled to conserve processing power.
Given the FreeRTOS Stream Buffer is ISR safe, the interrupt will always be active when the buffer is not empty.

The callback function is shown below:
```c
void vSerial_RxCallback(StreamBufferHandle_t xStreamBuffer,
                        BaseType_t xIsInsideISR,
                        BaseType_t *const pxHigherPriorityTaskWoken) {
    (void) xStreamBuffer;
    (void) xIsInsideISR;
    (void) pxHigherPriorityTaskWoken;
    // Enable all active ports with full buffers
    for (int i = 0; i < eSerialN; i++) {
        // Enable the TX interrupt if the serial state is OK and there is a TX
        // buffer attached, and that buffer contains data elements to be read
        if (SerialPort[i].state == eSerialOK && SerialPort[i].tx_buf != NULL) {

            size_t bytes_avail =
                xStreamBufferBytesAvailable(SerialPort[i].tx_buf);
            if (bytes_avail > 0)
                hal_uart_enable_txne(SerialPort[i].UART, true);
        }
    }
}
```

## ISR (Interrupt Service Routine)
The UART interface uses a single interrupt for both RX and TX events.
All UART interfaces share a generic handler that processes RX, TX, and ORE (Over Run Error) events.

```c
void generic_handler(Serial_t *pHndl) {
    // MUST read status to clear ORE/NF/FE flags
    uint32_t status = hal_uart_read_status(pHndl->UART);
    BaseType_t higher_woken = pdFALSE;

    // Interrupt Generated for Read
    if (status & USART_SR_RXNE || status & USART_SR_ORE) {
        // MUST read input port to clear iPending bit
        uint8_t rx_data = hal_uart_read_byte(pHndl->UART);
        // hal_uart_write_byte(pHndl->UART, rx_data);
        // Check that a handler exists
        if (pHndl->rx_buf == NULL || pHndl->state != eSerialOK) {
            // If there is no handler disable this interrupt
            hal_uart_enable_rxne(pHndl->UART, false);
            return;
        }
        // If a buffer exists, run the interrupt routine
        xStreamBufferSendFromISR(
            pHndl->rx_buf, &rx_data, sizeof(rx_data), &higher_woken);
    }
    if (status & USART_SR_TXE && pHndl->UART->CR1 & USART_CR1_TXEIE) {
        if (pHndl->tx_buf == NULL || pHndl->state != eSerialOK) {
            // If there is no handler disable this interrupt
            hal_uart_enable_txne(pHndl->UART, false);
            return;
        }
        uint8_t tx_data = 0;
        if (xStreamBufferReceiveFromISR(
                pHndl->tx_buf, &tx_data, 1, &higher_woken) == 1) {
            hal_uart_write_byte(pHndl->UART, tx_data);
        } else {
            hal_uart_enable_txne(pHndl->UART, false);
        }
    }
    portYIELD_FROM_ISR(higher_woken);
}
```

If ORE events are not processed, the interrupt will not exit.
The ORE flag is currently ignored, but still must be cleared.
The ORE flag is cleared by first reading the status register, then reading the data register.

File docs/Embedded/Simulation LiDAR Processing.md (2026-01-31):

Documentation for the "Scout" Simulation LiDAR Processing Task.
This task was used to verify the functionality of the LiDAR design and serve as a framework for implementing the RpLiDAR processing task.

> **WARNING:**
> This module is still under construction.
> Only preliminary testing has been performed, and while this testing was successful, the data processing method is subject to change.
{:.prompt-warning}

## Overview
The Simulation LiDAR task is responsible for processing incoming LiDAR data from the USB interface.
It serves as both a verification of the processing method and as a template for future LiDAR processing tasks.

The task is designed to process LiDAR data one USB packet at a time.
As packets arrive, the following sequence of actions is taken:
1. A Local Collision Vector is computed based on the LiDAR points in the packet
2. The local collision vector is stored in the local collision vector array
3. The local collision vector array is used to compute the global collision vector
4. The global collision vector is sent to the control task for obstacle avoidance

## Data Processing

### LiDAR Data Input
Whereas a real LiDAR processing task would handle receiving data from the actual LiDAR sensor, the simulation task reads simulated LiDAR data from the USB interface with the following code snippet.

```c
// Attempt to pull the latest packet from the incoming process queue
static struct udev_pkt_lidar ldrpkt = {0};
if (xQueueReceive(pHndl->usb.rx, &ldrpkt, 100) != pdTRUE) {
    // Input Queue Empty
    printf("Lidar Input Queue Empty\n");
    continue;
}
```

### Local Collision Vector Calculation
After receiving the LiDAR data, the task processes the packet independently to calculate the local collision vector.
This is performed by looping over all points in the packet, using its identifier information to calculate the effective angle for each point.

```c
float sum_x = 0.0f;
float sum_y = 0.0f;
float ground_sum = 0.0f;
float ceil_sum = 0.0f;
int valid_points = 0;
for (int i = 0; i < ldrpkt.hdr.len; i++) {
    float d = (float) ldrpkt.distances[i] / 4000.0f;
    if (d > 45.0f || d < 0.1f) {
        continue;
    }
    valid_points++;
    float angle = udev_lidar_angle(ldrpkt.hdr.sequence, i);
    float weight = 1.0f / d;
    float cos = cosf(angle);
    sum_x += weight * cos;
    if (cos < 0) {
        ground_sum += fabsf(d * cos);
    } else {
        ceil_sum += fabsf(d * cos);
    }
    sum_y += weight * sinf(angle);
}

// Dont bother processing packets with no points
if (valid_points == 0) {
    continue;
}
```

Note that the processing loop ignores out of range points, and LiDAR packets that do not contain any valid points.

### Recording Local Collision Vectors
After calculating the local collision vector, the task adds it into its global array.
This allows LiDAR packets to be received and processed out of order without reordering.

```c
// Add the new resultant sum depending on lidar orientation
if (ldrpkt.hdr.id == eLidarFront) {
    pHndl->sums_front[ldrpkt.hdr.sequence].x = sum_x;
    pHndl->sums_front[ldrpkt.hdr.sequence].y = sum_y;
    pHndl->sums_front[ldrpkt.hdr.sequence].z = 0.0f;
    pHndl->sums_front[ldrpkt.hdr.sequence].w = 0.0f;
}
if (ldrpkt.hdr.id == eLidarVertical) {
    pHndl->sums_vertical[ldrpkt.hdr.sequence].x = 0.0f;
    pHndl->sums_vertical[ldrpkt.hdr.sequence].y = sum_y;
    pHndl->sums_vertical[ldrpkt.hdr.sequence].z = sum_x;
    pHndl->sums_vertical[ldrpkt.hdr.sequence].w = 0.0f;
    pHndl->ceil_sums[ldrpkt.hdr.sequence] = ceil_sum;
    pHndl->ground_sums[ldrpkt.hdr.sequence] = ground_sum;
}
```

### Global Collision Vector Calculation
Finally, the task loops over the local vector array, now containing the newly updated segment, and calculates the global collision vector.
This vector can then be sent to the control task for obstacle avoidance.

```c
// Calculate the collision vector
ctrl_state_t cs;
cs.cv.x = 0;
cs.cv.y = 0;
cs.cv.z = 0;
cs.cv.w = 0;
cs.ground_distance = 0;
cs.ceil_distance = 0;

for (int i = 0; i < UDEV_LIDAR_SEQ_MAX; i++) {
    for (int j = 0; j < 4; j++) {
        cs.cv.data[j] += pHndl->sums_vertical[i].data[j];
        cs.cv.data[j] += pHndl->sums_front[i].data[j];
    }
    cs.ground_distance += pHndl->ground_sums[i];
    cs.ceil_distance += pHndl->ceil_sums[i];
}

// Send CV to control task
xQueueOverwrite(pHndl->cvtx.hndl, &cs);
```

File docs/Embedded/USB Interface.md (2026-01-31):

**USB Interface:** Documentation for the "Scout" USB CDC-ACM (Common Device Class - Abstract Control Model) interface built using FreeRTOS and [Dmitry Filimonchuk's `libusb_stm32`](https://github.com/dmitrystu/libusb_stm32).

The Scout USB interface utilizes Dmitry Filimonchuk's `libusb_stm32` Hardware Abstraction Layer (HAL).
It is designed to be event driven, utilizing FreeRTOS queues to safely offload data processing to FreeRTOS tasks.
This allows near complete separation between the tasks and the USB interface code.

## Device Specifications
The following section details the high-level device specifications, shown from the viewpoint of the host as per USB IF specifications.
- Vendor ID: `0xFFFE`
- Product ID: `0xD40C`
- Control Endpoint (CDC-ACM)
	- NTF Interface Number: `0x00`
	- Data Interface Number: `0x01`
	- Data RX EP: `0x01`
	- Data TX EP: `0x81`
	- Maximum Data Packet Size: `0x40`
	- NTF EP: `0x82`
	- Maximum NTF Packet Size: `0x08`
- LiDAR Endpoint (CDC-ACM)
	- NTF Interface Number: `0x02`
	- Data Interface Number: `0x03`
	- Data RX EP: `0x03`
	- Data TX EP: `0x83`
	- Maximum Data Packet Size: `0x40`
	- NTF EP: `0x84`
	- Maximum NTF Packet Size: `0x08`

### Endpoint Descriptions
#### Control Endpoint
The control endpoint is configured as a CDC-ACM endpoint designed for the exchange of control data between the control board and a higher level controller.
The endpoint expects different packets for RX (Receive) and TX (Transmit) events.
The TX packet (shown below) describes the expected data format of control commands sent to the control board from the high-level host.

```c
struct udev_pkt_ctrl_tx {
    union {
        struct {
            float x, y, z, w;
        };
        float data[4];
    } vel;
    uint8_t mode;
} __attribute__((packed, aligned(4)));
```

A description of the command structure is provided below:
- `vel` - Velocity Command
	- `x` - Forwards/Reverse Velocity Command (-1 to 1)
	- `y` - Sideways Velocity Command (-1 to 1)
	- `z` - Height Velocity Command (-1 to 1)
	- `w` - Yaw/Rotate Velocity Command (-1 to 1)
- `mode` - Request Mode Change (`enum eCBMode`)

Note that the `mode` field is described within the command structure as a `uint8_t` to ensure identical bit widths between the embedded device and host controller.
In practice, the `mode` field should be interpreted as a member of the `eCBMode` enumeration (shown below).

```c
enum eCBMode {
    eModeStalled,
    eModeRC,
    eModeNormal,
    eModeSim,
    eModeFault
};
```

The RX packet (shown below) describes the data format sent from the control board to the high-level host.

```c
struct udev_pkt_ctrl_rx {
    union {
        struct {
            float x, y, z, w;
        };
        float data[4];
    } vel;
    uint8_t vBatt;
    uint8_t rssi;
    uint8_t status;
    uint8_t mode;
} __attribute__((packed, aligned(4)));
```

A description of the command structure is provided below:
- `vel` - Actual Velocity command that was forwarded to the drone Flight Controller (FC)
	- `x` - Forwards/Reverse value currently applied to the FC (-1 to 1)
	- `y` - Sideways value currently applied to the FC (-1 to 1)
	- `z` - Height value currently applied to the FC (-1 to 1)
	- `w` - Yaw/Rotate currently applied to the FC (-1 to 1)
- `vBatt` - Battery Voltage in $\frac{V}{4}$
- `rssi` - Received Signal Strength Intensity from controller (0 to 100%)
- `status` - Control Board Status (`enum eCBStatus`)
- `mode` - Current Control Board Mode (`enum eCBMode`)

Again, note that the `mode` and `status` fields are described as `uint8_t` to ensure identical bit widths between the embedded device and the high-level host controller.
Both fields should be interpreted as members of `enum eCBMode` and `enum eCBStatus` respectively.

#### LiDAR Endpoint
The LiDAR endpoint is configured as a CDC-ACM endpoint designed for bidirectional and unidirectional exchange of LiDAR data between the control board and higher level controller.
Given that LiDAR stream data is typically larger than the maximum USB packet size (`0x40` or 64 bytes), the data packets used within the LiDAR endpoint have been designed to support unordered LiDAR data transmission.
As a result, LiDAR data may be transmitted or received out of order, but can be processed without reordering.
The LiDAR endpoint can be operated in one of two modes (Simulation or Normal), configured via the `mode` parameter sent inside of the control endpoint.

**Simulation Mode:**
When operating in Simulation mode, the LiDAR endpoint is used for bidirectional data exchange.
In this mode, the Control Board expects to receive simulation LiDAR data from the LiDAR endpoint.
The Control Board will then be able to use the simulated LiDAR data as if it were real data.
While in Simulation Mode, all other LiDAR endpoint functionality is still enabled.
Thus, the transmission of LiDAR data to the high-level controller can be tested while in Simulation Mode.

**All/Normal Mode(s):**
In all modes, the LiDAR endpoint acts as a unidirectional endpoint, transmitting LiDAR data captured from the LiDAR input (either sensors or simulation).
This enables the high-level control device to gain direct access to the LiDAR data being used for hover and collision control.

LiDAR packet formatting is universal for both RX and TX events.
The packet format is designed to handle 180 LiDAR points from two LiDAR data streams.
The packet format assumes all distance measurements are equidistant apart (2 deg for 180 points).

```c
enum eCBLidar {
    eLidarFront = 0U,
    eLidarVertical = 1U
};
struct udev_pkt_lidar {
    struct {
        uint8_t id : 1;
        uint8_t sequence : 7;
        uint8_t len;
    } __attribute__((packed)) hdr;
    uint16_t distance_sum;
    // distance (mm) = distance / 4.0
    uint16_t distances[UDEV_LIDAR_POINTS];
} __attribute__((aligned(4)));
```

A description of the LiDAR data packet is shown below:
- `hdr` - Header Data
	- `id` - ID of the LiDAR (`enum eCBLidar`)
	- `sequence` - Packet Sequence Number (0 to `UDEV_LIDAR_SEQ_MAX`)
	- `len` - Number of LiDAR distances in this packet
- `distance_sum` - *OPTIONAL* Average distance of all LiDAR distances in this packet
- `distances` - LiDAR measured distance in $\frac{mm}{4.0}$

Note that the LiDAR packet is configurable via the following definitions placed in the `usb_packet.h` header.

```c
#define UDEV_LIDAR_RANGE 180
#define UDEV_LIDAR_POINTS ((LIDAR_DATA_SZ - 4) / 2)
#define UDEV_LIDAR_SEQ_MAX ((UDEV_LIDAR_RANGE - 1 + UDEV_LIDAR_POINTS) / UDEV_LIDAR_POINTS)
```

Note that the `UDEV_LIDAR_POINTS` definition is configured to calculate the maximum number of distance points that can be placed within a single packet.
This number is calculated based on the maximum packet size (`0x40` or 64 bytes), the header size (2 bytes) and the size of `distance_sum` (2 bytes).

The following extraneous definitions and helper functions are also available within the `usb_lidar.h` header.

```c
#define UDEV_LIDAR_SEQ_STEP ((float) (3.1415926535f / (int) UDEV_LIDAR_SEQ_MAX))
#define UDEV_LIDAR_ITER_STEP ((float) (UDEV_LIDAR_SEQ_STEP / (int) UDEV_LIDAR_POINTS))

/**
 * @brief Calculate the angle of a given seq number and iterator
 *
 * @param seq Packet Sequence Number
 * @param iterator Packet Iterator Number
 * @return
 */
static inline float udev_lidar_angle(int seq, int iterator) {
    return (float) ((float) seq * UDEV_LIDAR_SEQ_STEP +
                    (float) iterator * UDEV_LIDAR_ITER_STEP);
}

/**
 * @brief Calculate the seq and iterator for a given angle
 * * @param angle    The input angle in radians
 * @param out_seq  Pointer to store the calculated sequence number
 * @param out_iter Pointer to store the calculated iterator/index
 */
static inline void udev_lidar_index(float angle, int* out_seq, int* out_iter) {
    int global_index = (int) ((angle / UDEV_LIDAR_ITER_STEP) + 0.5f);
    *out_seq = global_index / UDEV_LIDAR_POINTS;
    *out_iter = global_index % UDEV_LIDAR_POINTS;
}
```

These functions allow for simplistic conversions between the LiDAR packet structure and conventional angle-based structures.

## Implementation
The following section details the implementation and usage of the USB interface layer designed for the Scout Control Board.

### Initialization
The USB interface can be initialized by calling the `usbi_init(void)` function.
This function must only be called once by the `Init` routine present in `main`.

The initialization function serves two purposes.
First, it sets up the USB hardware to contain the appropriate endpoints and descriptions for host interfacing.
Second, it sets up and returns the FreeRTOS stream buffers used for USB-Task communication.

#### Hardware Initialization
Most of the hardware initialization is covered by [Dmitry Filimonchuk's `libusb_stm32`](https://github.com/dmitrystu/libusb_stm32).
The small portion remaining covers initializing the USB GPIO pins, enabling the correct interface within the library, and configuring the USB endpoint callbacks.

#### FreeRTOS Queue Initialization
The USB interface utilizes four FreeRTOS queues for interrupt-task communication.
Two queues are used for each USB endpoint, and are initialized with the following code snippet:

```c
usbi.lidar_rx = xQueueCreateStatic(USBI_LIDAR_BUF_SIZE,
									sizeof(struct udev_pkt_lidar),
									(uint8_t *) usbi_lidar_rx_buf,
                                    &usbi_lidar_rx_sqh);

usbi.lidar_tx = xQueueCreateStatic(USBI_LIDAR_BUF_SIZE,
                                    sizeof(struct udev_pkt_lidar),
                                    (uint8_t *) usbi_lidar_tx_buf,
                                    &usbi_lidar_tx_sqh);

usbi.ctrl_tx = xQueueCreateStatic(USBI_CTRL_BUF_SIZE,
                                    sizeof(struct udev_pkt_ctrl_tx),
                                    (uint8_t *) usbi_ctrl_tx_buf,
                                    &usbi_ctrl_tx_sqh);

usbi.ctrl_rx = xQueueCreateStatic(USBI_CTRL_BUF_SIZE,
									sizeof(struct udev_pkt_ctrl_rx),
		                            (uint8_t *) usbi_ctrl_rx_buf,
		                            &usbi_ctrl_rx_sqh);
```

All queue data storage is statically initialized within the USB interface.
Queue handles are returned by the `usbi_init` function through a `struct usbi*`, which points to internal USB memory.
This structure and its members should not be made globally accessible.
Rather, the Queue handles present within the structure should be locally distributed to the correct tasks during the initialization phase.

### Internal Event Handling
This subsection explains how the USB layer internally handles USB events.
#### Control Event Handling
The following internal callback is used by the USB layer to handle RX and TX events that occur on the Control Endpoint.
To ensure that the control data being exchanged with the high-level controller is the most recent available, the callback uses `xQueueOverwrite` and a queue size of `1`.
This queue size must not be changed, or `xQueueOverwrite` may fail.

```c
static void ctrl_rxtx(usbd_device *dev, uint8_t evt, uint8_t ep) {
    BaseType_t higher_woken = pdFALSE;
    if (evt == usbd_evt_eprx) {
        struct udev_pkt_ctrl_tx pkt_ctrl_tx = {0};
        (void) usbd_ep_read(
            dev, ep, (void *) &pkt_ctrl_tx, sizeof(struct udev_pkt_ctrl_tx));
        (void) xQueueOverwriteFromISR(usbi.ctrl_tx,
                                      &pkt_ctrl_tx,
                                      &higher_woken);

    } else {
        struct udev_pkt_ctrl_rx pkt_ctrl_rx = {0};
        if (xQueueReceiveFromISR(usbi.ctrl_rx, &pkt_ctrl_rx, &higher_woken) == pdTRUE) {
            (void)usbd_ep_write(dev,
                          ep,
                          (void *) &pkt_ctrl_rx,
                          sizeof(struct udev_pkt_ctrl_rx));
        } else {
            (void)usbd_ep_write(dev, ep, (void *) &pkt_ctrl_rx, 0);
        }
    }
    portYIELD_FROM_ISR(higher_woken);
}
```

#### LiDAR Event Handling
The following internal callback is used by the USB layer to handle RX and TX events that occur on the LiDAR Endpoint.
Unlike the Control Endpoint, the LiDAR endpoint uses a medium size queue to handle large burst transfers of LiDAR data.
Additionally, the LiDAR endpoint does not contain any retry logic, and will drop packets when the LiDAR packet queue is full.

```c
static void lidar_rxtx(usbd_device *dev, uint8_t evt, uint8_t ep) {
    BaseType_t higher_woken = pdFALSE;
    struct udev_pkt_lidar pkt_lidar = {0};
    if (evt == usbd_evt_eprx) {
        usbd_ep_read(
            dev, ep, (void *) &pkt_lidar, sizeof(struct udev_pkt_lidar));
        // Dont worry about dropping packets
        (void) xQueueSendToBackFromISR(usbi.lidar_rx,
                                       &pkt_lidar,
                                       &higher_woken);
    } else {
        if (xQueueReceiveFromISR(usbi.lidar_tx, &pkt_lidar, &higher_woken) ==
            pdTRUE) {
            usbd_ep_write(
                dev, ep, (void *) &pkt_lidar, sizeof(struct udev_pkt_lidar));
        } else {
            usbd_ep_write(dev, ep, (void *) 0, 0);
        }
    }
    portYIELD_FROM_ISR(higher_woken);
}
```

### External Event Handling
This subsection explains how USB events should be handled externally by FreeRTOS tasks.

#### Control Event Handling
The control event queue is designed to always contain the most recent control commands.
Thus, if the queue is empty, the embedded device has not received a new control command.

Therefore, RX events can be handled as follows:
```c
if (xQueueReceive(pHndl->col_rx, &ct, 0) == pdTRUE) {
	// Process the Control Event
}
```

Additionally, TX events can be sent to the host with:

```c
struct udev_pkt_ctrl_rx pkt_rx = (struct udev_pkt_ctrl_rx) {0};
// Load Data
(void) xQueueGenericSend(pHndl->usb.rx, &pkt_rx, 1, queueOVERWRITE);
```

When transmitting packets back to the host, ensure that the `queueOVERWRITE` flag is used.
Otherwise, the task may hang waiting for the USB host to request a control packet.
Using the above methods, neither the USB host or device are required to wait for data.

#### LiDAR Event Handling
LiDAR packets may be delivered out-of-order, therefore, any task that handles LiDAR events must be able to handle out-of-order packets.
Note that the simulation LiDAR task does not reorder packets.
For more information, consult the Simulation LiDAR Processing documentation.

Receiving simulation LiDAR data can be performed as follows:
```c
static struct udev_pkt_lidar ldrpkt = {0};
if (xQueueReceive(pHndl->usb.rx, &ldrpkt, 100) != pdTRUE) {
    // Input Queue Empty
    printf("Lidar Input Queue Empty\n");
    continue;
}
```

Transmitting LiDAR packets to the host can be done as follows provided the LiDAR data is pre-arranged into the packet.

```c
// Send the newly processed packet over USB for ROS LaserScan
(void) xQueueSendToBack(pHndl->usb.tx, &ldrpkt, 10);
```

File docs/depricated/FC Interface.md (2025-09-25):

The Flight Controller (FC) interface serves as a middle ware for basic events:
- Arming/Disarming
- Setting target velocities
*Note:*
- The Flight controller relies on the MSP and CSRF interfaces to communicate with the drone.
- The FC interface task is not required to perform flight kinematics.
- The FC interface task is not required to run PID loop calculations
	- This is handled automatically by the gravitational controller
- The FC interface task is required to monitor control timeouts and prevent the FC from timing out
- On the event of a failure, the FC task should:
	1. Notify higher level control
	2. Center all control values (make the drone hover in place)
	3. Perform rapid controlled decent

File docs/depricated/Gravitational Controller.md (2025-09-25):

Gravitational control is a method for path execution that assigns a "gravity" to all points in the workspace.
The corresponding "gravity" values can then be turned into vectors acting on the drone.
After normalising, the vectors can be summed to find the movement vector the drone should take.

The gravitational controller on the drone is responsible for:
- Fetching LiDAR Data
- Changing LiDAR data into gravitational fields/vectors
- Inclusion of the destination/target point or velocity
- Outputting the movement vector the drone should take.

The gravitational controller must be able to work with fixed point values (applied as masses), and velocity values (applied during the vector summation step).

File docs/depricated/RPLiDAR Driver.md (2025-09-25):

The RPLiDAR driver is a software abstraction between the LiDAR UART interface and the rest of the software.
It should:
- Communicate with the LiDAR through the STM32 UART driver (may be called Serial)
- Provide point cloud data to the rest of the software through an interface with realised SI units
- Be able to set up the LiDAR for scanning
- Change basic settings and perform basic configuration options

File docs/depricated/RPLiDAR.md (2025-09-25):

The RPLiDAR C1M1 is a compact 360-degree 2D laser scanner (LIDAR) that provides 2.5D multidimensional information, including position and reflectivity data. Its scanning frequency of 10Hz enables a sample rate of 5KHz and precise angular resolution of 0.72°. With a 12-meter measurement radius and a sampling frequency of 5000 times per second, it is suitable for robot positioning, mapping, navigation, and obstacle avoidance.
[Source](https://www.seeedstudio.com/RPLiDAR-C1M1-R2-Portable-ToF-Laser-Scanner-Kit-12M-Range-p-5840.html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)

## Info
-  [Datasheet](https://d229kd5ey79jzj.cloudfront.net/3157/SLAMTEC_rplidar_datasheet_C1_v1.0_en.pdf)
- TTL UART (`460800` BAUD) - Datasheet Pg 14
- Pinout - Datasheet Pg 12
	- VCC (5V)
	- TX (3v3)
	- RX (3v3)
	- GND

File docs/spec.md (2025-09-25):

# Project Specifications
This document describes the purpose of the project and sets some basic design goals.

## Purpose
The purpose of this project is to design an autonomous UAV capable of mapping tight spaces without colliding into obstacles or requiring a GNSS signal.

## Design Goals
### Autonomous Operation
The UAV must be able to operate fully autonomously, requiring only an initial and final input from an operator to start and stop the program.

### Mapping and Localization
The UAV must be able to traverse unknown environments without the use of GNSS signals for localization.
While traversing these environments, the UAV must be able to construct a map of its surroundings.
The constructed map must use scientific units and contain a virtualized 3D representation of the explored environment.
The UAV must make an attempt to explore as much of the environment as possible.
All explored areas of the environment should be added to the map.
The program must return the map to the operator on program completion.

### Collision Avoidance
While navigating, the UAV must be capable of avoiding collisions within the environment.
A collision is defined as any part of the UAV coming into direct physical contact with the environment during autonomous navigation.
Exceptions to the above exist when the UAV is performing an action that requires contact with the environment during situations such as landing and takeoff.

### Telemetry and Radio Communication
The UAV must be able to operate without the usage of any radio signals communicating with external hardware including but not limited to: GNSS signals, Base Station links, or wireless controller inputs.

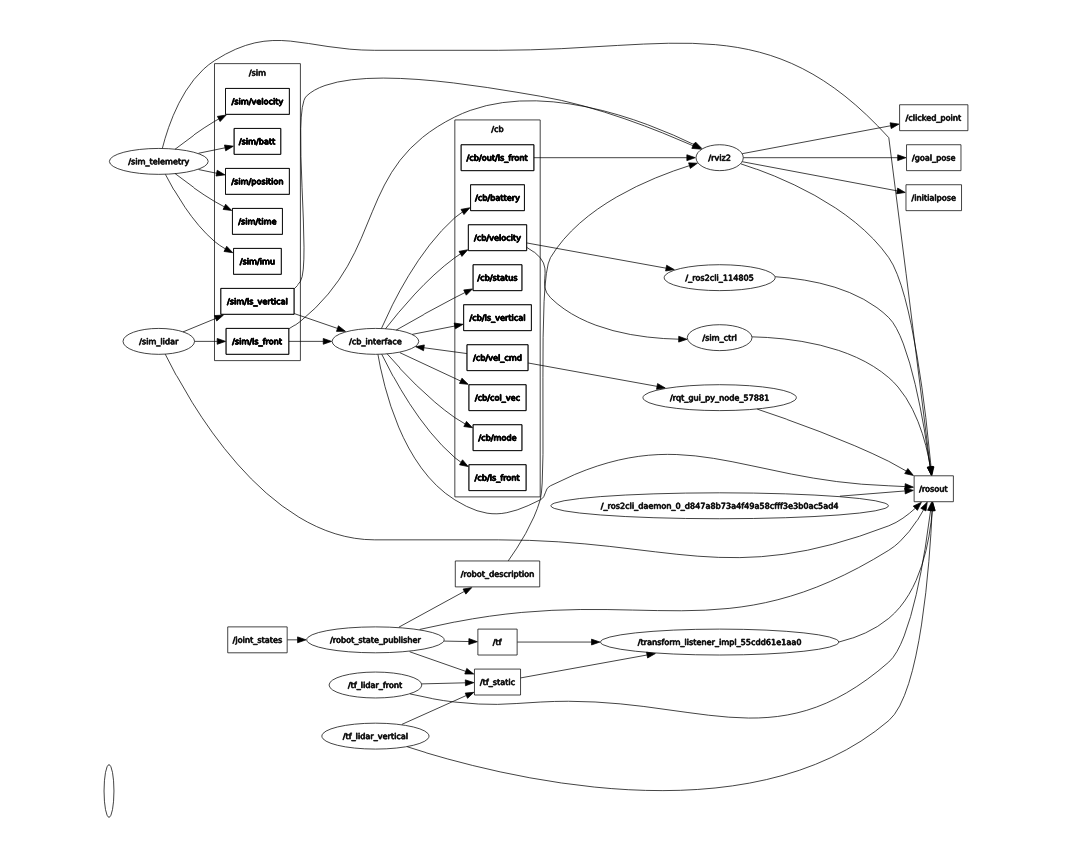
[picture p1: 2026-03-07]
docs/all ros topics.png

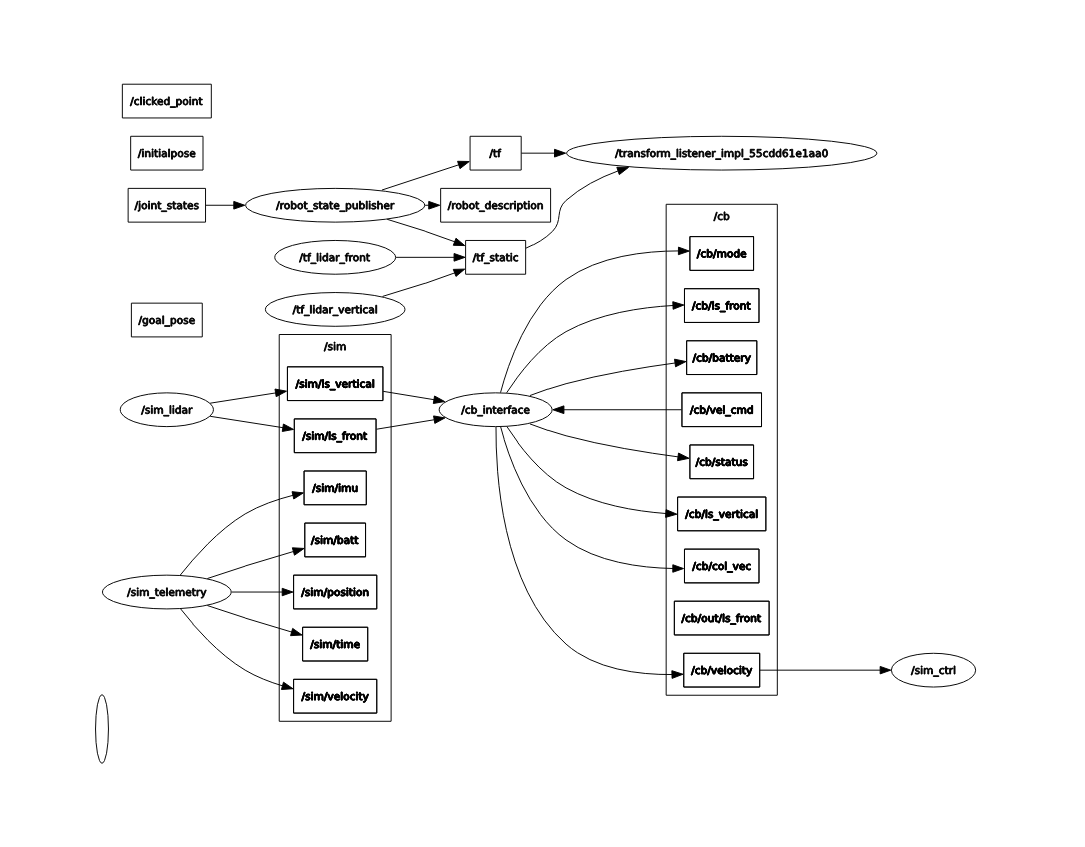
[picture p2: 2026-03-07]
docs/ros sim graph.png

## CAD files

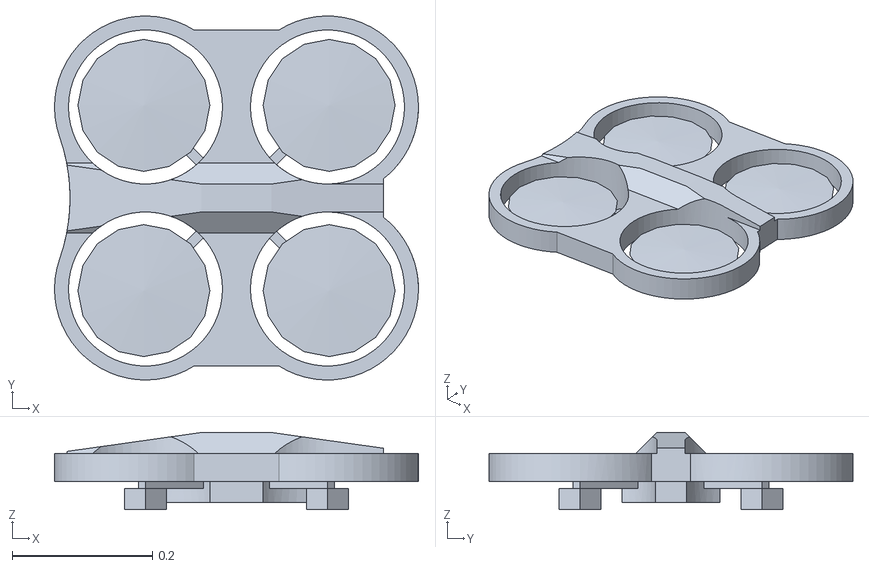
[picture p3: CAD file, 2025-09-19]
src/simulation/udrf/quadrotor_4.stl
0.52 x 0.52 x 0.11

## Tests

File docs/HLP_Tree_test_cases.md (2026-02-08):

Asssuming:
- closeness threshold = 2

Test:
AddPoint(0, 0) // Start Point
// Tree now contains 0, 0
GetNext() -> (0, 0)
// Add next open points
AddPoint(3, 0.5)
AddPoint(3, -0.5)
// Tree now contains one of the two nodes from above
// One is removed due to radius constraints
GetNext() -> (3, {-0.5, 0.5})
// Add hallway points
AddPoint(4, -3)
AddPoint(4, 4)
// Pick new direction to go in
GetNext() -> (4, 4)
// See end of hallway
AddPoint(5, 8)
// Pick new direction to go in
GetNext() -> (5, 8)
// Reach end of hallway
// See beginning of hallway
AddPoint(4, 6)
// Node is not added, node is within the distance threshold of the path
// Distance threshold of path is distance from point to line
// No new nodes
// Leaf node reached, go back n
GetNext() -> (4, 4)
// go back n
GetNext() -> (3, {-0.5, 0.5})
// This node still has (3, -3) unexplored
GetNext() -> (3, -3)
// Reach end of hallway
// No new nodes
// Leaf node reached, go back n
GetNext() -> (3, {-0.5, 0.5})
// go back n
GetNext() -> (0, 0)
// At end
GetNext() -> (0, 0)
GetNext() -> (0, 0)

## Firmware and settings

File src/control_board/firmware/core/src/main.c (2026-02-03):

/**
 * @file main.c
 * @author Jacob Chisholm (https://Jchisholm204.github.io)
 * @brief ELEC 498 Capstone - Central Control Board
 * @version 0.2
 * @date Created: 2025-1-19
 * @modified Last Modified: 2026-01-12
 *
 * @copyright Copyright (c) 2025
 */

#include "main.h"

#include "FreeRTOS.h"
#include "config/FreeRTOSConfig.h"
#include "config/pin_cfg.h"
#include "os/syscalls.h"
#include "os/systime.h"
#include "stm32f446xx.h"
#include "task.h"

#include <memory.h>
#include <stdio.h>
#include <string.h>

// Driver Includes
#include "drivers/serial.h"

// USB Includes
#include "usb/usb_interface.h"

// Task Includes
#include "tasks/ctrl_tsk.h"
#include "tasks/gravity_planner_tsk.h"
#include "tasks/sim_lidar_tsk.h"
#include "tasks/test_tsks.h"

// Task Structures
struct ctrl_tsk ctrl_tsk;
struct gplan_tsk gplan_tsk;
struct sim_lidar_tsk sim_lidar_tsk;
struct test_tsk test_tsk;

// Initialize all system Interfaces
void Init(void) {
    // Initialize System Clock
    hal_clock_init();

    // Init USB Interface
    struct usbi *usbi = usbi_init();

    // Initialize UART
    Serial_t *Serial3 =
        serial_init(eSerial3, /*baud*/ 115200, PIN_USART3_RX, PIN_USART3_TX);
    Serial_t *Serial2 =
        serial_init(eSerial2, /*baud*/ CRSF_BAUD, PIN_USART2_RX, PIN_USART2_TX);
    Serial_t *Serial5 =
        serial_init(eSerial5, /*baud*/ CRSF_BAUD, PIN_UART5_RX, PIN_UART5_TX);

    // Register Serial Port 3 as STDIO
    // (Use this serial port for printf)
    register_stdio(Serial3);

    /**
     * Initialize System Tasks...
     * All tasks should be initialized as static
     * Tasks can be initialized dynamically, but may crash the system if they
     * overflow the system memory (128Kb for the STM32f446)
     */
    test_tsk_init(&test_tsk, 1000);
    // QueueHandle_t slqh =
    //     gplan_tsk_init(&gplan_tsk, usbi->lidar_rx, usbi->lidar_tx);
    CtrlQueueHndl_t slqh =
        sim_lidar_tsk_init(&sim_lidar_tsk, usbi->lidar_rx, usbi->lidar_tx);
    ctrl_tsk_init(&ctrl_tsk, Serial2, Serial5, usbi->ctrl_rx, usbi->ctrl_tx, slqh);

    return;
}

int main(void) {
    // Call the init function
    Init();

    // Required ..?
    NVIC_SetPriorityGrouping(3);

    // Start Scheduler: Runs tasks initialized above
    vTaskStartScheduler();

    // System Main loop (Should never run -> Scheduler runs infinitely)
    for (;;) {
        asm("nop");
        // gpio_write(PIN_LED2, true);
    }
    return 0;
}

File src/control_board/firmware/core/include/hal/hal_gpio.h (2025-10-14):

#pragma once

#include <stdint.h>
#include <stdbool.h>
#include <sys/stat.h>

#include "stm32f4xx.h"
#include "hal_clock.h"
#include "pin.h"


#define GPIO(bank) ((GPIO_TypeDef *) (GPIOA_BASE + 0x400U * (bank)))
enum GPIO_MODE_IO   { GPIO_MODE_INPUT, GPIO_MODE_OUTPUT, GPIO_MODE_AF, GPIO_MODE_ANALOG };
enum GPIO_PULL_MODE { GPIO_RESET, GPIO_PULLUP, GPIO_PULLDOWN};
// See STM32 Manual pg180
enum GPIO_AF_MODE {
    GPIO_AF_SYS = 0,
    GPIO_AF_TIM1 = 1,
    GPIO_AF_TIM2 = 1,
    GPIO_AF_TIM3_5 = 2,
    GPIO_AF_TIM8_11 = 3, 
    GPIO_AF_I2C = 4, 
    GPIO_AF_SPI = 6, 
    GPIO_AF_UART = 7, 
    GPIO_AF_CAN = 9,
    GPIO_AF_USB = 10,
};

enum GPIO_SPEED {
    GPIO_SPEED_LS = 0,
    GPIO_SPEED_MS = 1,
    GPIO_SPEED_FS = 2,
    GPIO_SPEED_HS = 3,
};

/**
 * @brief Set the PinMode of a GPIO Pin
 * 
 * @param pin PIN(bank, number)
 * @param mode GPIO_MODE::<INPUT, OUTPUT, AF, ANALOG>
 */
static inline void gpio_set_mode(uint16_t pin, enum GPIO_MODE_IO mode) {
    GPIO_TypeDef *gpio = GPIO(PINBANK(pin));
    int n = PINNO(pin);
    SET_BIT(RCC->AHB1ENR, (uint32_t)(1UL << PINBANK(pin)));       // Enable GPIO clock
    gpio->MODER &= (uint32_t)~(3U << (n*2));
    gpio->MODER |= (uint32_t)((mode & 3U) << (n * 2));   // Set new mode

}

/**
 * @brief Set GPIO Alternate Function
 * 
 * @param pin 
 * @param af_num 
 */
static inline void gpio_set_af(uint16_t pin, enum GPIO_AF_MODE af) {
    GPIO_TypeDef *gpio = GPIO(PINBANK(pin));
    int n = PINNO(pin);
    gpio->AFR[n >> 3] &= (uint32_t)~(15UL << ((n & 7) * 4));
    gpio->AFR[n >> 3] |= (uint32_t)((uint32_t) af) << ((n & 7) * 4);
}

static inline void gpio_set_speed(pin_t pin, enum GPIO_SPEED speed){
    GPIO_TypeDef *gpio = GPIO(PINBANK(pin));
    int n = PINNO(pin);
    gpio->OSPEEDR &= (uint32_t)~(0x3UL << ((n & 7) << 1));
    gpio->OSPEEDR |= (uint32_t)~(speed << ((n & 7) << 1));
}

/**
 * @brief Write a Digital Value to a pin
 * 
 * @param pin PIN(bank, number)
 * @param value <true, false>
 */
static inline void gpio_write(uint16_t pin, bool value) {
    GPIO_TypeDef *gpio = GPIO(PINBANK(pin));
    gpio->BSRR = (uint32_t)((1UL << PINNO(pin)) << (value ? 0 : 16));
}

static inline void gpio_toggle_pin(uint16_t pin){
    GPIO_TypeDef *gpio = GPIO(PINBANK(pin));
    gpio->BSRR = (uint32_t)((1UL << PINNO(pin)) << (gpio->ODR & (1UL << PINNO(pin)) ? 16 : 0));
}

static inline bool gpio_read_idr(uint16_t pin) {
    const GPIO_TypeDef *gpio = GPIO(PINBANK(pin));
    return (bool)((gpio->IDR >> PINNO(pin)) & 0x1UL);
}

static inline bool gpio_read_odr(uint16_t pin){
    const GPIO_TypeDef *gpio = GPIO(PINBANK(pin));
    return (bool)((gpio->ODR >> PINNO(pin)) & 0x1UL);
}

static inline void gpio_pull(uint16_t pin, enum GPIO_PULL_MODE mode){
    GPIO_TypeDef *gpio = GPIO(PINBANK(pin));
    gpio->PUPDR &= (uint32_t)~(3U << (PINNO(pin)*2));
    if(mode!=GPIO_RESET) gpio->PUPDR |= (uint32_t)(mode << (2*(PINNO(pin))));
}

// t: expiration time, prd: period, now: current time. Return true if expired
static inline bool timer_expired(volatile uint32_t *t, uint32_t prd, uint32_t now) {
  if (now + prd < *t) *t = 0;                    // Time wrapped? Reset timer
  if (*t == 0) *t = now + prd;                   // First poll? Set expiration
  if (*t > now) return false;                    // Not expired yet, return
  *t = (now - *t) > prd ? now + prd : *t + prd;  // Next expiration time
  return true;                                   // Expired, return true
}

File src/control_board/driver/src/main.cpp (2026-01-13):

#include <rclcpp/rclcpp.hpp>
#include <std_msgs/msg/float32.hpp>
#include "driver/driver.hpp"

#include <unistd.h>
#include <stdbool.h>
#include <memory.h>
#include <libusb-1.0/libusb.h>


int main(int argc, char **argv) {
    printf("Hello World\n");
    rclcpp::init(argc, argv);
    rclcpp::spin(std::make_shared<Driver>());
    rclcpp::shutdown();
    return 0;
}

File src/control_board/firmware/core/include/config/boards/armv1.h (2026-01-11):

/**
 * @file armv1.h
 * @author Jacob Chisholm (https://Jchisholm204.github.io)
 * @brief Pin Mappings for STM Nucleo F446ZE
 * @version 0.1
 * @date 2024-10-12
 * 
 * @copyright Copyright (c) 2024
 * 
 */

#ifndef _PINS_ARMV1_H_
#define _PINS_ARMV1_H_
#include "hal/pin.h"
#define _BOARD_CONFIG_


// LED Pins
#define PIN_LED1      PIN('C', 8)
#define PIN_LED2      PIN('C', 9)
#define PIN_LED3      PIN('A', 8)

// USART/UART Pins
#define PIN_USART3_TX PIN('C', 10)
#define PIN_USART3_RX PIN('C', 11)

#define PIN_UART5_TX  PIN('C', 12)
#define PIN_UART5_RX  PIN('D', 2)

// CAN Pins
#define PIN_CAN1_RX   PIN('B', 8)
#define PIN_CAN1_TX   PIN('B', 9)

#define PIN_CAN2_RX   PIN('B', 5)
#define PIN_CAN2_TX   PIN('B', 6)

// USB Pins
#define PIN_USB_VBUS  PIN('A', 9)
#ifndef USBD_VBUS_DETECT
#define USBD_VBUS_DETECT
#endif
#define PIN_USB_DM    PIN('A', 11)
#define PIN_USB_DP    PIN('A', 12)

// Motor Control
// #define PIN_MTR_EN    PIN('D', 2)
#define PIN_MTR_PWM1  PIN('A', 2) // TIM 9 Ch 1
#define PIN_MTR_PWM2  PIN('A', 5) // Tim 2 Ch 1

// Arm Tooling
#define PIN_TOOL_LP1  PIN('C', 2)
#define PIN_TOOL_LP2  PIN('A', 0)
#define PIN_TOOL_A1   PIN('C', 3)
#define PIN_TOOL_A2   PIN('A', 1)

// Arm Limit Switches
#define PIN_LSW_1     PIN('B', 15)
#define PIN_LSW_2     PIN('B', 15)
#define PIN_LSW_3     PIN('B', 12)
#define PIN_LSW_4     PIN('C', 7)
#define PIN_LSW_5     PIN('B', 14)
#define PIN_LSW_6     PIN('B', 13)

// Servos
// #define PIN_SRVO_EN   PIN('C', 12)
// TIM3 CH 1
#define PIN_SERVO_1   PIN('A', 6)
// TIM3 CH 2
#define PIN_SERVO_2   PIN('A', 7)
// TIM3 CH 3
#define PIN_SERVO_3   PIN('B', 0)
// TIM3 CH 4
#define PIN_SERVO_4   PIN('B', 1)

#endif

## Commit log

2025-09-18 lidar works
2025-09-19 rviz wip
    [quadrotor_4.stl, sjtu_drone.sdf, sjtu_drone.urdf]
2025-09-19 rviz vizes
    [quadrotor_4.stl, sjtu_drone.sdf, sjtu_drone.urdf]
2025-09-20 jetson build
2025-09-20 t lidar swap
2025-09-21 arm wip
2025-10-17 wip uart5 fixes
2025-10-17 uart5 fixed
2025-12-12 adding pcb altium
2025-12-12 adding pcb
2025-12-13 pcb changes
2025-12-14 updated mcu schematic
    [MCU.SchDoc, PCB1.PcbDoc, PCB_Project.PrjPcb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]
2026-01-11 started simulation links
    [quadrotor_4.stl, sjtu_drone.sdf, sjtu_drone.urdf]
2026-01-13 usb driver wip
2026-01-14 switched to one lidar usb queue
2026-01-14 Fix Heisenbug - UART ORE
    - Added in VScode debugging launch for RTOS Views
    - Increased the main stack size to avoid interrupt routine overflows
    - Increased task stack sizes
    - Added a status read to the USART interrupt - Main Heisenbug fix
    - Added `trace.c` to setup the ITM trace and SWO
    - Added NVIC priority group call (explicit call, should be called by
    FreeRTOS)
    - `-fno-omit-frame-pointer` forces all functions to use a dedicated
    frame pointer
2026-01-15 lidar loopback
2026-01-15 lidar packet updates
2026-01-15 op lidar data method
2026-01-15 CRITICAL USART ORE Fix
    [serial.c]
2026-01-16 vertical lidar working
2026-01-16 switch to dedicated sim tasks
2026-01-30 switch pcb to new repo
    [MCU.SchDoc, PCB1.PcbDoc, PCB_Project.PrjPcb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]
2026-02-01 better control flow
2026-02-01 lidar fund broke
2026-02-02 lidar process rework
2026-02-04 laser segmentation
2026-02-08 eric tree planner test case
